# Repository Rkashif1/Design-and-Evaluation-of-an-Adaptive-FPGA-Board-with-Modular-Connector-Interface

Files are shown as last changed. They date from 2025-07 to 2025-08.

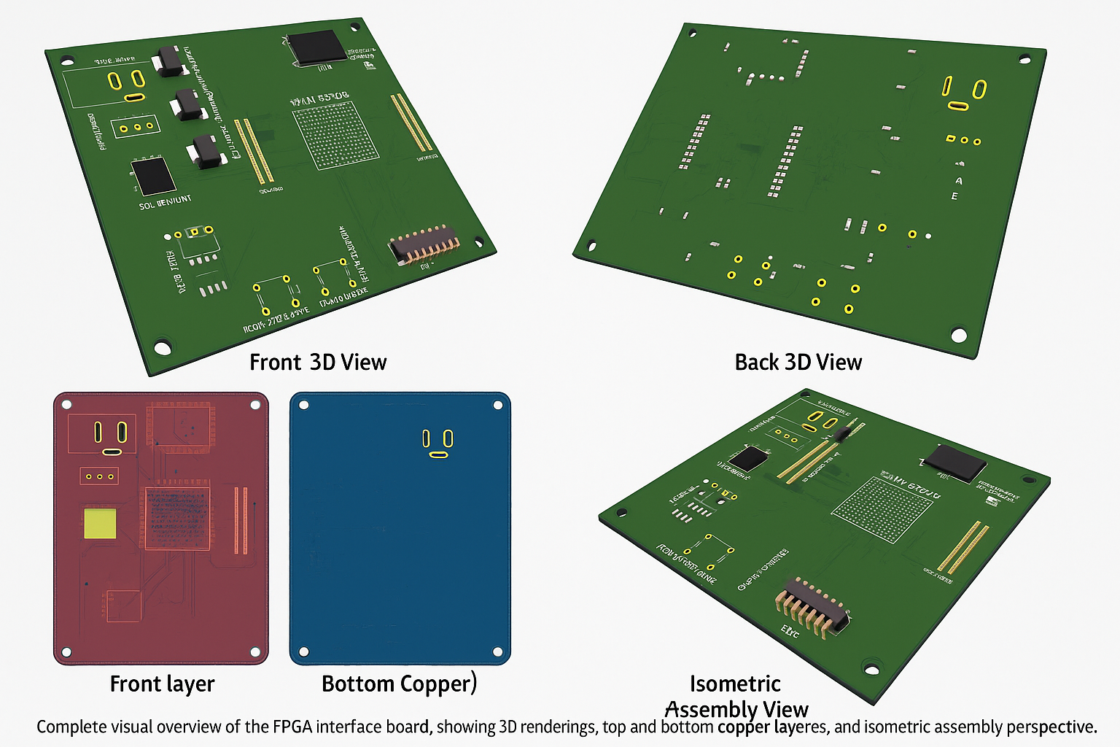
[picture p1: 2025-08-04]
Project_Refrence_Images/Others/FPGA Interface Board 3D Overview.png

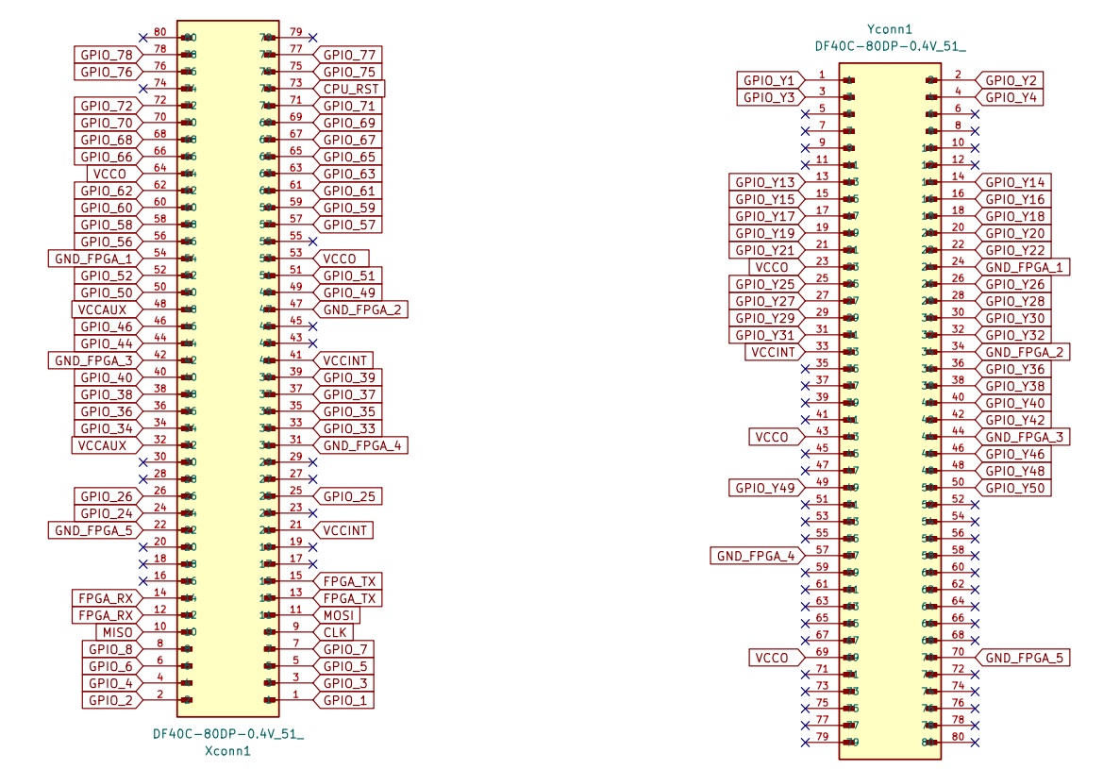
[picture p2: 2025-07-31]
Project_Refrence_Images/Schematics/DFC_Connectors.jpg

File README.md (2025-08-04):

**Design and Evaluation of an Adaptive FPGA Board with Modular Connector Interface**

This repository contains the complete project files for the development of an adaptive FPGA board designed to interface with various sensor and actuator peripherals through dual high-density connectors. The FPGA module is implemented using the Xilinx Spartan-7 XC7S25 and follows a modular architecture that allows it to be plugged into different motherboards for dynamic reconfiguration.

📁 Contents include:

KiCad schematic and PCB layout files

LaTeX report and documentation

Schematics and 3D board Refrence Images

🛠️ Key tools used: KiCad, Xilinx Vivado, Git, LaTeX

📌 Developed as part of an academic project demonstrating real-world modular hardware design and reconfigurable embedded systems.

FPGA Interface Board 3D Overview
*3D rendered view of the adaptive FPGA board featuring dual high-density connectors and a Spartan-7 FPGA*

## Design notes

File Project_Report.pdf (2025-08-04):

## Design and Evaluation of an Adaptive FPGA Board with Modular Connector Interface

Project Work by

### Kashif Raza

In Partial Fulfillment of the Requirements for the Degree of
Bachelor of Engineering - ELECTRONICS

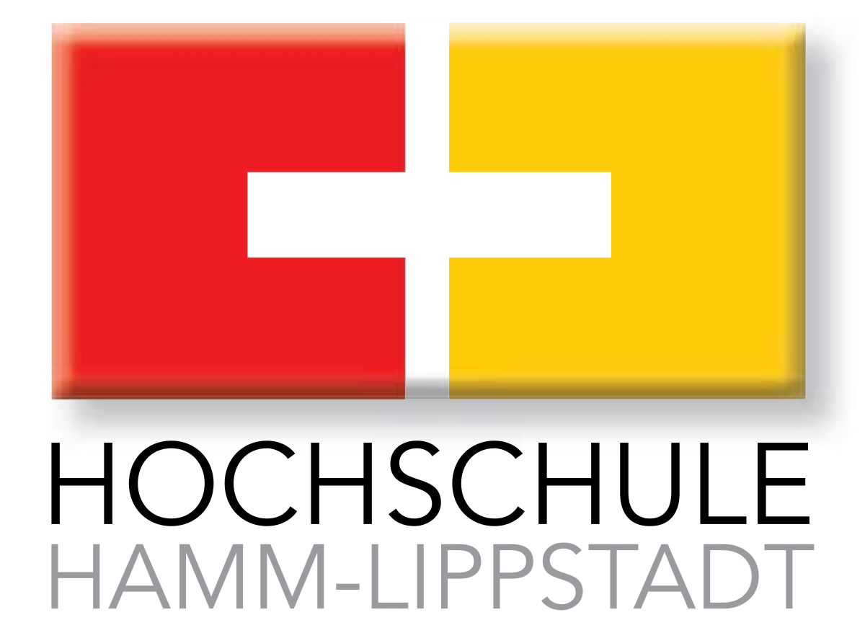
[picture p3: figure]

HOCHSCHULE HAMM-LIPPSTADT

First University Examiner: Prof. Dr. -Ing. Ali Hayek !!!!
Submission Date 31/07/2025

ii

© First University Examiner: Prof. Dr. -Ing. Ali Hayek

© !!!!

iii

### ACKNOWLEDGEMENTS

I would like to express my sincere appreciation to everyone who supported me in completing my project work. I am particularly thankful to my examiner, Professor Ali Hayek, for his continuous guidance and encouragement throughout the process. Through his courses on Hardware Engineering and Advanced Hardware Engineering, I gained the essential theoretical knowledge and practical understanding required to design and implement a custom FPGA-based adaptive board and develop a complete PCB layout.

Professor Hayek’s emphasis on precision and structured thinking helped me approach this project with a clear and calculated mindset. I am grateful for the academic environment provided by Hamm-Lippstadt University of Applied Sciences, which fostered my growth and enabled me to independently explore and apply concepts in real-world PCB and FPGA system design.

iv

### ABSTRACT

This project presents the design and implementation of an adaptive FPGA-based interface board centered on the Xilinx Spartan-7 XC7S25, developed as a compact, modular, and scalable platform for embedded systems and robotics applications. The primary goal was to identify and integrate the most suitable FPGA solution that balances performance, cost, toolchain accessibility, and long-term availability. After a comparative evaluation of multiple FPGA families, the Spartan-7 was selected for its modern 28 nm architecture, low power consumption, and full support within the free Vivado WebPACK environment. The board features two 80-pin DF40C high-density connectors that enable seamless integration with external motherboards or expansion units, along with support for DDR2 memory, SPI and UART communication, and dedicated interfaces for sensors and actuators. Configuration and debugging are facilitated through onboard USB-UART and JTAG interfaces, while basic I/O interaction is supported via LEDs and push buttons. Implemented on a multilayer PCB, the design ensures efficient signal routing, stable power delivery, and domain separation for reliable operation. Tailored for educational and prototyping contexts, the board accommodates typical robotics tasks such as line-following, obstacle detection, and servo control, offering a flexible and accessible foundation for FPGA-based system development.

v

### TABLE OF CONTENTS

Acknowledgements | iii
Abstract | | iv
Table of Contents | | v
List of Illustrations | | vi
Chapter I: Introduction | | 1
1.1 Motivation | | 1
Chapter II: Project Requirements and Design Goals | | 3
Chapter III: Selecting the Right FPGA Solution | | 4
Chapter IV: Features | | 7
Chapter V: Applications of the Adaptive FPGA Board | | 8
Chapter VI: Pin Mapping | 10
6.1 X-CONN Pin Mapping | 12
6.2 Y-CONN Pin Mapping | 14
Chapter VII: Peripherals | 16
Chapter VIII: Schematic and PCB Overview | 19
Chapter IX: Evaluation | 23
Chapter X: Future Work | 25
Chapter XI: Tools and Software Used | 27
Bibliography | 28

vi

### LIST OF ILLUSTRATIONS

Number | Page
3.1 Xilinx Spartan-7 FPGA Package | | | 6
9.1 Design Rule Check completed successfully | 24
8.1 Schematic: Power Management and Voltage Regulation Block | 31
8.2 Schematic: USB-UART and SPI Communication Interface Block | 32
8.3 Schematic: Xilinx JTAG Configuration Interface Block | 32
8.4 Schematic: External Memory Module Support Block | 33
8.5 Schematic: Reset and Power LED Indicator Block | 34
8.6 Schematic: Clock Generation with Crystal Oscillator | 35
8.7 Schematic: DF40C High-Density Connector Interface | 35
8.8 Schematic: Xilinx Spartan-7 FPGA Core Block | 36
8.9 3D View of Final PCB - Front Side | 37
8.10 3D View of Final PCB - Back Side | 38
8.11 Top View of Final PCB Layout | 39
8.12 Bottom View of Final PCB Layout | 40
8.13 Isometric View of the Assembled Board | 41
8.14 Layer Stackup | 42

C h a p t e r 1

### INTRODUCTION

In the field of embedded systems, Field Programmable Gate Arrays (FPGAs) play a crucial role due to their parallel processing capabilities, reconfigurability, and suitability for time-critical applications. Unlike microcontrollers, FPGAs offer hardware-level concurrency, making them ideal for robotics, signal processing, and control systems.

This project presents the design of an adaptive FPGA-based interface board built around the Xilinx Spartan-7 XC7S25. The board is developed as a modular platform to support a variety of sensor and actuator-driven systems. Key features include external DDR2 memory, SPI and UART communication interfaces, JTAG and USB-UART programming options, and onboard peripherals such as LEDs and push buttons. To facilitate expandability and integration, the board includes two 80-pin DF40c high-density connectors that allow reliable interfacing with external control units. A multilayer PCB layout is used to ensure clean separation of power, signal, and ground domains.

This document is organized to guide the reader through the complete development process. The initial chapters cover the motivation, design goals, and FPGA selection strategy. Subsequent sections describe the hardware features, application domains, and detailed pin mapping for both high-density connectors. The later chapters focus on peripheral integration, schematic and PCB layout overview, design evaluation, and future development directions, concluding with the tools used throughout the project.

### 1.1 Motivation

The motivation behind this project came from the growing demand for compact, modular hardware platforms suited for academic and prototyping environments. In university labs, developers often need to experiment with various sensors, actuators, and communication protocols. Designing a general-purpose adaptive board reduces the need to create custom hardware for each use case, saving time and increasing flexibility.

FPGAs, particularly from the Spartan-7 family, offer the reconfigurability, low power consumption, and logic capacity necessary for mid-range embedded applications. Unlike microcontrollers, they enable parallel processing and custom logic implementation, making them ideal for tasks that require real-time performance. To support clean integration with external systems, the board includes DF40c high-density connectors and is built on a multilayer PCB to ensure signal integrity and reduce noise. Robotics applications were a key focus, with dedicated sensors, actuators, and communication modules.

The project combines practical PCB design experience with embedded system development, resulting in a reusable FPGA-based platform tailored for academic, research, and robotics use cases.

C h a p t e r 2

### PROJECT REQUIREMENTS AND DESIGN GOALS

The goal of this project is to design a compact, low-power, and cost-effective embedded system based on the Xilinx Spartan-7 XC7S25 FPGA, tailored for educational, prototyping, and small-scale deployment use. The platform is designed to interface with a wide range of sensors, communication peripherals, and memory components, while remaining reusable and scalable.

A key requirement was selecting an FPGA with sufficient logic density, low power consumption, and broad I/O support, while ensuring compatibility with a free and accessible development toolchain. The Spartan-7 series met these criteria and supports features such as DDR2 memory, SPI, I²C, and

UART communication.

To maximize modularity, the board integrates high-density DF40c connectors for expansion with external modules like motor drivers or wireless interfaces. The layout also considers future scalability by supporting pin-compatible FPGA upgrades within the Spartan-7 family.

Essential onboard peripherals including push buttons, LEDs, and oscillator circuits—support development and debugging. The use of a multilayer PCB enhances signal integrity and power distribution. All components were chosen with long-term availability in mind, making the board suitable for replication in academic and research settings.

The project’s design goals focused on building a reusable and expandable embedded platform with a strong emphasis on performance, cost-efficiency, educational usability, and peripheral integration. These requirements drove every architectural and component-level decision made throughout the course of development.

C h a p t e r 3

### SELECTING THE RIGHT FPGA SOLUTION

Choosing the most suitable FPGA for a development board requires careful evaluation of multiple factors: logic capacity, I/O availability, toolchain compatibility, power consumption, costeffectiveness, and long-term availability. These considerations become even more critical when designing an educational or prototyping-focused platform where usability, affordability, and futureproofing are essential.

In the early stages of this project, multiple FPGA families were considered, including Intel’s Cyclone IV and V series, Lattice’s iCE40 lineup, and Xilinx’s Spartan-6 and Spartan-7 families. Each candidate offered unique advantages and trade-offs, which were evaluated across the metrics shown in Table 3.1.

Table 3.1: Comparison of FPGA Families Considered

FPGA Family | Logic Cells | Block RAM | Tool Support | Power | Open Source?
Intel Cyclone IV Intel Cyclone V Lattice iCE40 HX8K Xilinx Spartan-6 LX25 Xilinx Spartan-7 XC7S25 | 22,000 30,000 7,680 24,051 23,360 | 1.2 Mbits 2.5 Mbits 128 Kbits 936 Kbits 1,600 Kbits | Quartus Quartus Prime Yosys + nextpnr ISE (Legacy) Vivado | Moderate Moderate-High Very Low Moderate Low | No No Yes No No

The Xilinx Spartan-7 XC7S25-1FTGB196C FPGA was selected for this project due to its strong balance of modern architecture, low power consumption, flexible packaging, and long-term scalability. Among several evaluated options—such as Intel Cyclone IV/V, Lattice iCE40, and the older Spartan-6, the Spartan-7 family stood out as a future-ready and efficient solution that is well-suited for embedded development tasks. Built on a 28 nm process node, Spartan-7 FPGAs benefit from lower dynamic power consumption and support higher operational clock frequencies, all while maintaining a compact footprint. This is particularly advantageous in thermally-constrained or battery-powered embedded systems, as the device’s core voltage (VCCINT) is approximately 1.0 V, reducing overall thermal output and enabling efficient energy usage [14].

Technical Capabilities

The XC7S25 variant includes:

- 23,360 logic cells for implementing complex digital designs
- 1,600 Kbits of block RAM for buffering and temporary storage
- 80 DSP slices, allowing moderate digital signal processing operations

It supports interfacing with DDR2 SDRAM [13] and a wide range of I/O standards including LVCMOS, LVTTL, and LVDS [14]. These features make it ideal for control logic, memory expansion, and sensor or communication interfacing.

In addition to its base architecture, the Spartan-7 series includes several advanced integrated features that enhance its utility in complex applications. The inclusion of XADC allows for onchip voltage and temperature monitoring, which can be accessed via JTAG or user logic, aiding system diagnostics and dynamic reconfiguration. The device also incorporates MMCM and PLL clocking blocks, known as clock management tiles (CMT), which provide stable multi-domain clock generation critical for complex timing requirements. These features are all built on a unified 7-Series logic architecture, which is consistent across other Xilinx families such as Artix-7, Kintex-7, and Virtex-7, allowing for future design migration and scalability [14].

From a hardware design perspective, the FTGB196 BGA package was a strategic choice. Despite its compact size, it offers a sufficient number of I/O pins, allowing for high GPIO density while simplifying layout in multilayer PCB designs. Its fine-pitch ball grid array supports tight routing and reliable signal integrity, especially when paired with high-speed board-to-board connectors. The package’s compact footprint helps maintain a small overall board size while ensuring all necessary connections for sensors, memory, and communication peripherals can be made effectively [6].

Spartan-7 also proves to be a highly suitable option for academic and prototype-oriented projects. It is fully supported by the free Vivado WebPACK toolchain [16], which includes all essential features such as IP Integrator, constraint-based synthesis, simulation, and bitstream generation. This eliminates the need for costly software licenses, making it accessible to students and researchers. Compared to more resource-intensive solutions like Intel’s Cyclone V or Altera’s Stratix series, Spartan-7 enables a smoother learning curve without sacrificing critical FPGA development capabilities.

Scalability and Long-Term Availability

In terms of scalability and availability, the XC7S25 model is readily stocked by major global distributors including Digi-Key and Mouser [15]. This ensures that projects relying on the chip can continue production without facing supply shortages. Additionally, the XC7S25 is often pin-compatible with larger Spartan-7 models such as the XC7S50, which enables seamless upgrades

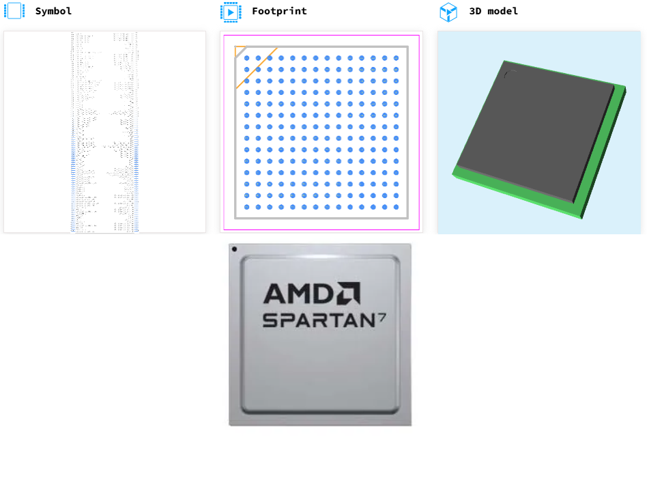
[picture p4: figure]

Figure 3.1: Xilinx Spartan-7 FPGA Package

in case future iterations of the project require more logic or memory resources. This upgradability reduces the need for PCB redesign and extends the long-term viability of the system architecture.

The Spartan-7 XC7S25 presents a well-rounded, accessible, and forward-compatible platform that meets the performance and flexibility demands of modern embedded system development. Its architectural features, robust toolchain support, and practical packaging make it a strong candidate for both initial prototyping and scaled deployment.

C h a p t e r 4

### FEATURES

The adaptive FPGA board was designed with a focus on modularity, flexibility, and expandability. Below are the key features that make this board suitable for embedded systems, robotics, and academic research:

- Xilinx Spartan-7 XC7S25 FPGA: Provides a strong balance of logic resources, low power

consumption, and modern toolchain support.

- Multilayer PCB Design: Ensures optimized signal integrity and power distribution across

functional layers.

- Two DF40c 80-pin High-Density Connectors: Allow secure and compact plug-and-play

connection to a motherboard or expansion board.

- Support for External DDR2 Memory: Enables high-speed memory interfacing for real-

time and data-intensive applications.

- Multiple Communication Interfaces: Includes dedicated lines for SPI, I2C, and UART

protocols to interface with various peripherals.

- JTAG Interface: Allows for easy programming and debugging of the FPGA using standard

tools.

- USB-UART Bridge: Facilitates serial communication with the FPGA for monitoring and

control.

- Onboard LEDs and Push Buttons: Offer user interaction and visual debugging during

testing and development.

- Peripheral Connector Support: Headers available for IR sensors, servo motors, ultrasonic

sensors, and OLED display.

- Compact and Student-Friendly Layout: Optimized for prototyping and academic use,

while remaining scalable for more complex designs.

- Cost-Efficient and Readily Available Components: Ensures that the board is affordable

and easy to reproduce for classroom or lab use.

C h a p t e r 5

### APPLICATIONS OF THE ADAPTIVE FPGA BOARD

The adaptive FPGA board has been designed to serve a wide range of applications in embedded systems, robotics, and automation. Because of its flexible I/O, memory support, and robust connectivity, it is suitable for both educational and real-world use cases. FPGAs have been increasingly adopted in domains where deterministic timing, parallel processing, and hardware-level customization are required [5, 9].

Some of the most relevant applications of this board are as follows:

- Line-Following Robot (LFR): Using onboard IR sensors, the FPGA can process line contrast

and control wheel motors accordingly. FPGAs are particularly well-suited for real-time signal processing required in robotics path planning [9].

- Obstacle Avoidance System: With the help of ultrasonic sensors (e.g., HC-SR04), the board

can be programmed to detect obstacles and react in real time by altering motor directions or triggering alerts.

- Robotic Arm Control: Through PWM generation on the FPGA, users can control servo

motors (such as SG90) for precise movement. The hardware-based timing control makes FPGAs better at handling simultaneous axis movement than software-based microcontrollers.

- Environmental Monitoring System: The board supports DHT22 sensors for temperature

and humidity monitoring, enabling use in smart home or industrial automation settings.

- IoT Gateway Node: By integrating with Wi-Fi (ESP8266) or Bluetooth (HC-05) modules

through UART or SPI, the FPGA board can function as a local processing and communication node in IoT systems.

- Data Acquisition and Display System: Data collected from sensors can be visualized

using the connected OLED (SSD1306) display, controlled via I2C from the FPGA, ideal for laboratory test setups.

- Educational FPGA Trainer Kit: With all essential interfaces onboard, the board is perfect

for teaching students about digital design, interfacing, and embedded system development.

The deterministic and reconfigurable nature of FPGAs makes them highly suitable for embedded control systems, especially in scenarios where flexibility and real-time processing are required [4].

C h a p t e r 6

### PIN MAPPING

The pin mapping of the adaptive FPGA board is a critical part of its overall architecture. To establish reliable communication between the FPGA and external peripherals (such as sensors, actuators, and user interfaces), the board features two 80-pin DF40c high-density connectors, designated as X-CONN and Y-CONN.

In our design, the male connectors are soldered onto the adaptive FPGA board, while the corresponding female connectors are present on a separate motherboard that carries all the peripheral components—such as IR sensors, servo motors, distance sensors, seven-segment displays, keypads, BLE modules, and more. This physical arrangement allows the adaptive board to be plugged directly into the motherboard. The DF40c connectors act as a bridge, allowing every pin on the adaptive board to connect precisely with the component it is intended to control or read from.

Each pin on the male connector is mapped either to an FPGA general-purpose I/O pin or to a dedicated communication, power, or control signal. By referencing the detailed pin mapping tables for both X-CONN and Y-CONN (provided in the following pages), users can quickly identify which peripheral connects to which FPGA pin. This structured mapping supports modular development and ensures long-term maintainability and scalability.

Beyond the X-CONN and Y-CONN mappings, several other connections are also established on the adaptive board:

- Power Management: Multiple voltage domains are supported across the board. Pins are

allocated for VCCINT (1.3V), VCCAUX (1.8V), and VCCO (3.3V). These voltages power both the FPGA core and the I/O banks. Ground connections (GND) are distributed throughout both connectors to ensure stable power delivery and signal integrity.

- Communication Interfaces:

– SPI Interface: Includes SCK, MISO, and MOSI lines routed to the FPGA for communicating with devices like LoRa modules, flash memory, or sensor hubs.

– UART Lines: RX and TX lines are connected for BLE (HC-05) and Wi-Fi (ESP8266) modules, enabling wireless communication.

– I

2C Bus: SDA and SCL pins are provided for interfacing with devices such as OLED

displays or real-time clocks.

- Input/Output Peripherals:

– Multiple GPIO pins are assigned to LEDs (LED1–LED16), push buttons (PB1–PB5), and switches (SW1–SW16).

– PWM-capable GPIOs are used for controlling servo motors and for generating signals for the motor driver’s IN and EN pins.

- Reset and Clocking:

– A dedicated reset pin (CPU_RST) is connected to a push button to reset the FPGA.

– An external clock pin (CLK) is allocated for synchronous logic and communication protocols like SPI.

- Analog and Mixed-Signal Interfaces:

– ADC reference voltage pins (ADC VREF+ and VREF-) are mapped for precise analog measurements from sensors such as LDR, vibration sensors, and microphones.

This comprehensive pin mapping strategy ensures that the board can be used across a wide range of embedded systems and robotics projects without needing redesigns for each application. By simply plugging the adaptive board into a motherboard carrying the necessary peripherals, the system becomes ready for programming, prototyping, or deployment.

Below are the detailed pin mappings for both X-CONN and Y-CONN connectors:

### 6.1 X-CONN Pin Mapping

Female Connector Pin | Male Connector Pin | Peripheral name | FPGA PIN
X1 | X1 | Keypad R1 | GPIO_1
X2 | X2 | Keypad R2 | GPIO_2
X3 | X3 | Keypad R3 | GPIO_3
X4 | X4 | Keypad R4 | GPIO_4
X5 | X5 | Keypad C1 | GPIO_5
X6 | X6 | Keypad C2 | GPIO_6
X7 | X7 | Keypad C3 | GPIO_7
X8 | X8 | Keypad C4 | GPIO_8
X9 | X9 | SPI SCK | CLK
X10 | X10 | SPI MISO | MISO
X11 | X11 | SPI MOSI | MOSI
X12 | X12 | HC05 BLE RXD | FPGA_RX
X13 | X13 | HC05 BLE TXD | FPGA_TX
X14 | X14 | ESP8266 WLAN RXD | FPGA_RX
X15 | X15 | ESP8266 WLAN TXD | FPGA_TX
X16 | X16 | GPIO 1 | X
X17 | X17 | GPIO 2 | X
X18 | X18 | GPIO 3 | X
X19 | X19 | GPIO 4 | X
X20 | X20 | NC | NC
X21 | X21 | VIN | VCCINT
X22 | X22 | GND | GND_FPGA_5
X23 | X23 | NC | NC
X24 | X24 | LED 1 | GPIO_24
X25 | X25 | LED 2 | GPIO_25
X26 | X26 | LED 3 | GPIO_26
X27 | X27 | GPIO 5 | X
X28 | X28 | GPIO 6 | X
X29 | X29 | GPIO 7 | X
X30 | X30 | GPIO 8 | X
X31 | X31 | GND | GND_FPGA_4
X32 | X32 | VIN | VCCAUX
X33 | X33 | LED 4 | GPIO_33
X34 | X34 | LED 5 | GPIO_34
X35 | X35 | LED 6 | GPIO_35
X36 | X36 | LED 7 | GPIO_36
X37 | X37 | LED 8 | GPIO_37
X38 | X38 | LED 9 | GPIO_38
X39 | X39 | LED 10 | GPIO_39
X40 | X40 | LED 11 | GPIO_40
X41 | X41 | VIN | VCCINT
X42 | X42 | GND | GND_FPGA_3

Female Connector Pin | Male Connector Pin | Peripheral name | FPGA PIN
X43 | X43 | NC | NC
X44 | X44 | I2C SDA | GPIO_44
X45 | X45 | NC | NC
X46 | X46 | I2C SCL | GPIO_46
X47 | X47 | GND | GND_FPGA_2
X48 | X48 | VIN | VCCAUX
X49 | X49 | LED 12 | GPIO_49
X50 | X50 | LED 13 | GPIO_50
X51 | X51 | LED 14 | GPIO_51
X52 | X52 | LED 15 | GPIO_52
X53 | X53 | VSYS | VCCO
X54 | X54 | GND | GND_FPGA_1
X55 | X55 | NC | NC
X56 | X56 | Switch 1 | GPIO_56
X57 | X57 | Switch 2 | GPIO_57
X58 | X58 | Switch 3 | GPIO_58
X59 | X59 | Switch 4 | GPIO_59
X60 | X60 | Switch 5 | GPIO_60
X61 | X61 | Switch 6 | GPIO_61
X62 | X62 | Switch 7 | GPIO_62
X63 | X63 | Switch 8 | GPIO_63
X64 | X64 | VSYS | VCCO
X65 | X65 | Switch 9 | GPIO_65
X66 | X66 | Switch 10 | GPIO_66
X67 | X67 | Switch 11 | GPIO_67
X68 | X68 | Switch 12 | GPIO_68
X69 | X69 | Switch 13 | GPIO_69
X70 | X70 | Switch 14 | GPIO_70
X71 | X71 | Switch 15 | GPIO_71
X72 | X72 | Switch 16 | GPIO_72
X73 | X73 | RESET | CPU_RST
X74 | X74 | NC | NC
X75 | X75 | Push button 1 | GPIO_75
X76 | X76 | Push button 2 | GPIO_76
X77 | X77 | Push button 3 | GPIO_77
X78 | X78 | Push button 4 | GPIO_78
X79 | X79 | NC | NC
X80 | X80 | NC | NC

### 6.2 Y-CONN Pin Mapping

Female Connector Pin | Male Connector Pin | Peripheral name | FPGA PIN
Y1 | Y1 | Color sensor S0 | GPIO_Y1
Y2 | Y2 | Moisture sensor signal | GPIO_Y2
Y3 | Y3 | Color sensor S1 | GPIO_Y3
Y4 | Y4 | Color sensor S2 | GPIO_Y4
Y5 | Y5 | GPIO 9 | X
Y6 | Y6 | GPIO 10 | X
Y7 | Y7 | GPIO 11 | X
Y8 | Y8 | GPIO 12 | X
Y9 | Y9 | GPIO 13 | X
Y10 | Y10 | GPIO 14 | X
Y11 | Y11 | GPIO 15 | X
Y12 | Y12 | GPIO 16 | X
Y13 | Y13 | Buzzer | GPIO_Y13
Y14 | Y14 | Color sensor S3 | GPIO_Y14
Y15 | Y15 | Seven segment display (a) | GPIO_Y15
Y16 | Y16 | Seven segment display (b) | GPIO_Y16
Y17 | Y17 | Seven segment display (c) | GPIO_Y17
Y18 | Y18 | Seven segment display (d) | GPIO_Y18
Y19 | Y19 | Seven segment display (e) | GPIO_Y19
Y20 | Y20 | Seven segment display (f) | GPIO_Y20
Y21 | Y21 | Seven segment display (g) | GPIO_Y21
Y22 | Y22 | Color sensor Out | GPIO_Y22
Y23 | Y23 | VCC / +3V3 | VCCO
Y24 | Y24 | GND | GND_FPGA_1
Y25 | Y25 | Seven segment display (a1) | GPIO_Y25
Y26 | Y26 | Seven segment display (a2) | GPIO_Y26
Y27 | Y27 | Seven segment display (a3) | GPIO_Y27
Y28 | Y28 | Seven segment display (a4) | GPIO_Y28
Y29 | Y29 | Seven segment display (a5) | GPIO_Y29
Y30 | Y30 | Seven segment display (a6) | GPIO_Y30
Y31 | Y31 | Seven segment display (a7) | GPIO_Y31
Y32 | Y32 | Seven segment display (a8) | GPIO_Y32
Y33 | Y33 | GND | GND_FPGA_2
Y34 | Y34 | VCC | VCCINT
Y35 | Y35 | NC | NC
Y36 | Y36 | Motor driver IN2 | GPIO_Y36
Y37 | Y37 | NC | NC
Y38 | Y38 | Left IR sensor pin | GPIO_Y38
Y39 | Y39 | NC | NC
Y40 | Y40 | Right IR sensor pin | GPIO_Y40
Y41 | Y41 | NC | NC
Y42 | Y42 | Motor driver IN4 | GPIO_Y42

Female Connector Pin | Male Connector Pin | Peripheral name | FPGA PIN
Y43 | Y43 | VCC / +3V3 | VCCO
Y44 | Y44 | GND | GND_FPGA_3
Y45 | Y45 | NC | NC
Y46 | Y46 | PIR motion sensor | GPIO_Y46
Y47 | Y47 | NC | NC
Y48 | Y48 | LoRa G0 | GPIO_Y48
Y49 | Y49 | LoRa CS | GPIO_Y49
Y50 | Y50 | LoRa RST | GPIO_Y50
Y51 | Y51 | RFID CS | X
Y52 | Y52 | RFID RST | X
Y53 | Y53 | NC | NC
Y54 | Y54 | DHT22 temperature sensor pin | X
Y55 | Y55 | NC | NC
Y56 | Y56 | NC | NC
Y57 | Y57 | GND | GND_FPGA_4
Y58 | Y58 | NC | NC
Y59 | Y59 | Distance sensor trigger | D6
Y60 | Y60 | Motor driver IN1 | D1
Y61 | Y61 | Left servo signal | D5
Y62 | Y62 | Motor driver EnA | D0
Y63 | Y63 | Motor driver IN3 | D4
Y64 | Y64 | NC | NC
Y65 | Y65 | Motor driver EnB | D3
Y66 | Y66 | NC | NC
Y67 | Y67 | Right servo signal | D2
Y68 | Y68 | NC | NC
Y69 | Y69 | VCC / +3V3 | VCCO
Y70 | Y70 | GND | GND_FPGA_5
Y71 | Y71 | ADC VREF + | X
Y72 | Y72 | ADC VREF - | X
Y73 | Y73 | LDR | A0
Y74 | Y74 | Piezo vibration sensor | A4
Y75 | Y75 | Potentiometer 2 | A1
Y76 | Y76 | Distance sensor echo | D20
Y77 | Y77 | LED 16 | A2
Y78 | Y78 | Push button 5 | D21
Y79 | Y79 | Microphone analog pin | A3
Y80 | Y80 | NC | NC

C h a p t e r 7

### PERIPHERALS

This section details the critical peripherals designed into the adaptive FPGA board. Each component is selected to maximize modularity, performance, and suitability for reconfigurable and embedded system applications.

Power Management Circuit

The power management subsystem is responsible for regulating, distributing, and protecting voltage supplies to the various blocks on the FPGA board. It typically includes low-dropout voltage regulators (LDOs), Schottky diodes, and decoupling capacitors. This design enables the board to derive multiple regulated rails—such as 3.3V for I/O, 1.2V for FPGA core, and 2.5V for auxiliary peripherals—from a single USB 5V input or external supply. Power sequencing is critical: the FPGA core voltage must be stabilized before auxiliary and I/O voltages are enabled, to prevent latch-up or undefined behavior during configuration. In your adaptive board, this stable power foundation ensures safe operation of high-speed interfaces like DDR2 and SPI, and also protects the FPGA fabric during boot and resets. A power-good LED is connected to the 3.3V line to indicate readiness, assisting in visual verification during testing or production. Without a stable power subsystem, the FPGA logic may misconfigure or fail to boot entirely [2].

High-Density DF40C Connectors

Your board includes two DF40C 80-pin high-density board-to-board connectors that form the central bridge between the adaptive FPGA module and the external motherboard. These connectors expose nearly all general-purpose I/Os, communication lines, and power rails from the FPGA to the external system. This modular approach allows the same FPGA core to interface with different hardware subsystems—such as robotics controllers, sensors, or actuators—by simply plugging into a different baseboard. The DF40C series from Hirose is known for high-speed signal support, compact pitch (0.4 mm), and robust mechanical locking. The connectors make the board ideal for stacking applications and ensure impedance-controlled routing suitable for DDR2, SPI, and other synchronous interfaces. In this project, the connectors provide the main pathway for SPIcontrolled OLED displays, I2C sensor arrays, IR-based obstacle sensors, or even actuator control via UART-based motor drivers [10].

JTAG Interface

The Joint Test Action Group (JTAG) interface is essential for in-system configuration and debugging of the FPGA. It enables boundary-scan testing, logic configuration through bitstream upload, and post-configuration signal analysis. In your design, a standard 6-pin JTAG header is connected directly to the Spartan-7 FPGA and routed to the top layer for easy access. This interface works with tools like Xilinx Vivado and iMPACT to program the board and observe internal logic. For instance, when verifying the DDR2 controller or the SPI communication core, the JTAG allows you to set breakpoints, toggle test inputs, or read internal registers using Chipscope or ILA (Integrated Logic Analyzer) IPs. The presence of JTAG simplifies the development cycle and eliminates the need for external flash or USB interfaces during firmware prototyping [16].

USB-UART and SPI Communication Interfaces

The board includes dual communication interfaces: USB-UART and SPI. The USB-UART bridge (such as a CP2102 or FT2232) connects the FPGA to a host PC via a virtual COM port, allowing real-time data exchange, logging, and user input through terminal applications like PuTTY. In your case, this is especially useful for logging events like configuration status, memory usage, or sensor data from the external motherboard. SPI (Serial Peripheral Interface), on the other hand, is a synchronous, full-duplex protocol ideal for interfacing with OLED displays, shift registers, and ADCs. On your adaptive board, the SPI lines are routed through the DF40C connector, enabling modular attachment to SPI-based peripherals like OLED or LoRa modules. The separation of control (UART) and sensor-actuator communication (SPI) ensures modularity, clarity in signal flow, and robust debugging [12, 7].

Memory Module Support

The board supports external DDR2 memory via a dedicated memory interface connected to the Spartan-7. The DDR2 SDRAM allows high-speed, large-volume data storage and buffering, which is essential for applications requiring frame buffering, temporary sensor data storage, or real-time signal processing. For example, in a use case where the FPGA is controlling a display or capturing sensor readings at high frequency, internal BRAM is insufficient. The DDR2 interface is implemented using the Xilinx MIG (Memory Interface Generator) IP, which handles timing constraints, clock domain synchronization, and latency management. This memory system enables your project to scale into more complex workloads, including lightweight video processing, packet buffering in IoT gateways, or real-time motor feedback systems [13].

LED Indicator and Reset Buttons

The board includes a single LED and two push buttons. The LED is connected to the 3.3V line through a resistor and serves as a power indicator. This is useful for basic health checking and user feedback, especially when operating headless (without PC connection). One push button is wired to the configuration reset pin, enabling reloading of the FPGA bitstream during debugging or recovery. The second button performs an FPGA CPU reset, which can be used to restart logic cores like MicroBlaze or user-defined FSMs without reprogramming the entire chip. Both buttons are active-low and debounced either through hardware (RC network) or logic (FPGA). In your modular system, these buttons help reset the board before re-attaching to new daughterboards or clearing memory states during demos [11, 8].

Crystal Oscillator

A 50 MHz crystal oscillator is included on the board to provide a clean, stable reference clock for the FPGA. The Spartan-7’s global clock input receives this signal and may use MMCMs (Mixed-Mode Clock Managers) or PLLs to derive secondary clocks (e.g., 100 MHz for memory, 25 MHz for SPI). Clock stability is critical for synchronous systems where timing violations can lead to metastability or data corruption. Your oscillator ensures reliable timing for DDR2 memory access, serial protocol timings, and logic state transitions. For example, when reading from sensors over SPI and writing to DDR2 buffers, synchronized and phase-aligned clocking ensures data coherency. The crystal is selected for low jitter and startup delay, suitable for both industrial and academic use [1].

FPGA Core: Xilinx Spartan-7

The computational engine of the board is the Xilinx Spartan-7 XC7S25-1FTGB196C FPGA. This 28nm CMOS programmable logic device offers 23,360 logic cells, 120 user I/Os, multiple block RAMs (BRAM), and dedicated DSP slices. It also includes integrated clock managers, high-speed serial transceivers, and support for MicroBlaze soft-core processors. In your adaptive system, this FPGA enables custom digital logic for tasks such as real-time sensor data processing, protocol bridging, and motor control. Its reconfigurability allows reuse across multiple applications—robotic control, IoT edge computation, or educational labs—by reprogramming the logic fabric. The Spartan-7 strikes a balance between cost, power, and capability, making it ideal for modular, reusable FPGA projects like yours [15].

C h a p t e r 8

### SCHEMATIC AND PCB OVERVIEW

This chapter provides a comprehensive description of the schematic design and PCB layout implemented for the adaptive FPGA board. The schematic is divided into functional blocks, each of which serves a specific purpose in the electrical and system-level design. These blocks are discussed below in the order they appear in the complete system.

The first subsystem is the Power Management and Voltage Regulation Block, which supplies the core voltage rails required by the FPGA and auxiliary components. The design includes low-dropout voltage regulators that convert a 5V USB input into stable 3.3V and 1.2V outputs. Proper decoupling capacitors are placed near each power pin, and the 3.3V line is connected to an indicator LED that signals the board’s power status. Input protection is provided by reverse-polarity diodes and inrush current-limiting resistors. This block ensures voltage stability and startup safety and lays the electrical foundation for all downstream modules. This block is shown in the Appendix as Figure 8.1.

The USB-UART and SPI Communication Block combines two vital communication protocols. The USB-UART section allows serial communication between the host computer and the FPGA, enabling terminal-based debugging and firmware logging. The SPI section enables the FPGA to control peripherals such as OLED displays and sensors. Pull-up resistors are included for SPI signal integrity, and all lines are routed through the DF40C connectors to external modules. The combined communication subsystem provides a flexible interface for both control and data flow. You can see the corresponding schematic in Figure 8.2 in the Appendix.

The JTAG Interface Block provides the programming and debugging entry point to the FPGA. It includes a 6-pin standard JTAG connector wired directly to the Spartan-7’s configuration pins. This block allows the user to upload bitstreams, perform boundary-scan testing, and use Xilinx debugging tools like Vivado’s Integrated Logic Analyzer. Proper signal terminations ensure clean JTAG clocking and reliable operation during configuration. This block is illustrated in Figure 8.3 in the Appendix.

The Memory Module Block includes routing for external DDR2 SDRAM, although the module is optional in this version. Control lines, address buses, and data I/Os are all grouped for synchronous timing and routed from the FPGA to the memory footprint. The goal of this module is to support data buffering for high-throughput applications in future versions of the board. The schematic layout for this module is shown in Figure 8.4 in the Appendix.

The Reset and LED Block features two push-buttons and one indicator LED. One push-button is connected to the FPGA configuration reset pin, and the other to the system reset input for internal soft-core processors like MicroBlaze. The LED is connected through a resistor to the 3.3V rail and confirms power delivery visually. These I/O elements are essential for manual testing, debugging, and system reinitialization. This schematic can be reviewed in Figure 8.5 in the Appendix.

The Clock Generation Block consists of a 50 MHz crystal oscillator connected to the FPGA’s global clock input. This stable reference clock feeds the Mixed-Mode Clock Manager (MMCM) inside the Spartan-7, which can then generate other required clock frequencies for different modules. Proper load capacitors and series resistors are included to ensure stable startup and reduce phase noise. This subsystem is critical for synchronous design and is depicted in Figure 8.6 in the Appendix.

The DF40C Connector Block implements the two 80-pin Hirose DF40C male connectors that allow the adaptive FPGA board to plug into a larger motherboard. All communication signals (SPI, UART, I2C), GPIOs, and power rails are routed through these connectors. The horizontal spacing between the connectors is 43.18 mm, matching the layout of the Arduino Portenta breakout board, ensuring mechanical and electrical compatibility. These connectors are the interface backbone that enables the board’s adaptive capabilities. The schematic is included in Figure 8.7 in the Appendix.

Lastly, the FPGA Core Block features the Xilinx Spartan-7 XC7S25 FPGA in an FTGB196 BGA package. It is connected to three separate power domains: VCCINT (1.2V core voltage), VCCAUX (2.5V auxiliary), and VCCIO (3.3V I/O). The block also includes all necessary configuration, global clock, and system reset lines. Most of the general-purpose I/O pins are routed through the DF40C connectors, allowing the board to adapt to various external peripheral arrangements. Proper pull-up and pull-down resistors are added to critical configuration pins such as INIT_B, DONE, and PROGRAM_B to ensure stable boot behavior and avoid floating logic states. This block serves as the heart of the adaptive system, enabling full reprogrammability and user-defined logic. The complete schematic for the FPGA core can be found in Figure 8.8 in the Appendix.

Following the completion of the schematic design, the next phase in the development process was the layouting. The transition from schematic to layout required careful consideration of electrical connectivity, mechanical constraints, component placement, and signal integrity. The board layout was created to house the Xilinx Spartan-7 XC7S25 FPGA along with all supporting peripherals, including power regulation circuits, communication interfaces, memory, clock sources, user I/O, and high-density connectors.

The first step in PCB layout involved defining the board outline and establishing the mechanical constraints dictated by the two DF40C high-density connectors. These connectors were placed precisely 43.18 mm apart to ensure compatibility with an external motherboard, similar to the Arduino Portenta breakout board. Mounting holes and connector footprints were then placed in accordance with the schematic, followed by strategic arrangement of core components such as voltage regulators, the JTAG interface, memory pads, and oscillator modules.

Once the component placement was finalized, the board stack-up was defined. Unlike simpler designs that rely on 2- or 4-layer PCBs, this adaptive FPGA board was implemented on a high-density 10-layer PCB. This multi-layer configuration allowed for optimized routing, dedicated power and ground planes, and controlled impedance paths for high-speed signals. The stack-up included alternating signal layers with interleaved power and ground planes to reduce electromagnetic interference (EMI) and crosstalk while maintaining electrical isolation between critical domains such as VCCINT, VCCAUX, and VCCIO.

The routing of the board was done using KiCad’s built-in routing tool, following custom rules for trace width, spacing, and via sizes. Important high-speed connections—like the ones used for the DDR2 memory and clock signals—were routed with carefully measured lengths to ensure they remain synchronized. In some cases, zig-zag or meandered traces were used to match signal timing. For signals that require high precision, like USB data lines, the traces were routed as balanced pairs on internal layers to reduce noise and maintain reliable communication.

The use of a ball-grid array (BGA) package for the Spartan-7 FPGA introduced significant routing challenges. With 196 balls and a high number of general-purpose I/O (GPIO) signals, careful fanout planning was essential. Blind, buried, and microvias were employed to escape inner balls and to reduce congestion under the BGA. Several inner layers were allocated specifically to facilitate this routing, providing additional channels for signals that could not be routed on outer layers. The inclusion of such via types enabled successful breakout and routing of all necessary FPGA signals to their corresponding blocks.

In addition to signal routing, several layers were reserved as solid planes for power distribution and grounding. This provided a low-impedance path for power delivery and improved thermal performance. Decoupling capacitors were placed as close as possible to the power pins of the FPGA and other active components, following standard high-speed design practices. Special attention was given to the oscillator block and clock lines, which were routed using short, shielded paths to minimize jitter and phase noise.

The visual inspection and review were complemented by 3D renderings of the board, which provided spatial verification of component heights, mounting hole clearance, and connector alignment. Screenshots of these 3D models are presented in Figures 8.9 to 8.13 in the Appendix for visual confirmation.

A major challenge faced during the PCB phase was the routing congestion caused by the dense peripheral configuration and the complexity of the FPGA chip. The abundance of signals, tight component spacing, and need for signal integrity required extensive layer planning and iterative routing. This phase was the most time-consuming and technically demanding part of the design, as even minor misroutes could cause timing issues, configuration failures, or mechanical misalignment.

Despite the challenges, the board was successfully routed, reviewed, and exported as Gerber files for manufacturing. The result is a professionally laid out, multi-layer PCB that meets the mechanical and electrical demands of an adaptive, reprogrammable embedded system. The design reflects a careful balance between technical precision and practical limitations of prototype development within the academic timeline.

C h a p t e r 9

### EVALUATION

After completing the PCB layout in KiCad, several evaluation steps were undertaken to validate both the electrical correctness and mechanical compatibility of the adaptive FPGA board. The first step involved running the built-in Design Rule Check (DRC) tool in the KiCad PCB editor. The DRC report, as shown in Figure 9.1, confirmed zero errors in the design, indicating that the trace widths, clearances, and via dimensions all adhered to the electrical constraints. Although some warnings were generated, mostly concerning the silkscreen layer, such as overlapping labels or proximity of silkscreen text to the board edge, these were acknowledged but not resolved due to time constraints, as they do not impact functionality or manufacturability.

Following the DRC validation, one of the most critical evaluations involved verifying the placement and alignment of the two high-density 80-pin DF40C male connectors on the bottom side of the adaptive FPGA board. These connectors form the primary physical and electrical bridge between the FPGA module and a separate motherboard that hosts peripherals like sensors, actuators, and communication bridges. To ensure successful interfacing, the connectors must match exactly with corresponding female connectors on the motherboard, both in horizontal spacing and vertical alignment. Any deviation in position could lead to mechanical failure or unreliable electrical contact.

To guide this mechanical alignment, the layout of the Arduino Portenta H7 breakout board was used as a dimensional reference. Although this project does not involve the Arduino board itself, the Portenta breakout board was chosen due to its documented and publicly available dimensions. According to the official documentation [3], the high-density connectors J1 and J2 on the breakout board are positioned at 17.14 mm and 60.32 mm, respectively, from the left edge of the PCB. Subtracting these values gives a connector spacing of 43.18 mm, which was then adopted in this design. This specific spacing ensures that the adaptive FPGA board can align with existing motherboard layouts that follow the same connector standard.

This 43.18 mm spacing was manually verified in the PCB layout by placing a dimension line between the connectors using the User.Drawings layer in KiCad. Additionally, the vertical alignment was also verified by ensuring both connectors shared the same Y-axis coordinate. Proper vertical alignment is crucial to avoid pin mismatch or physical stress during insertion into the motherboard.

This evaluation confirms the adaptive capability of the board. Once the FPGA is programmed with the correct bitstream, it can be inserted into the motherboard and immediately recognize and communicate with any connected peripherals via the DF40C connectors. The FPGA is configured to detect the data paths and act accordingly, making the board highly modular and reusable across different applications. The successful alignment of these connectors, along with a clean DRC result, verifies the integrity of the PCB design and validates its use in real-world adaptive embedded systems.

Finally, all electrical connections implemented in both the schematic and PCB layout were carefully designed in accordance with the official datasheets and reference manuals of the electronic components used. This includes the pin mappings, voltage supply lines, decoupling requirements, signal terminations, and communication interfaces. Adherence to component specifications ensures reliable electrical behavior and system stability under real operating conditions. This approach also minimizes the risk of hardware failures during integration with the motherboard and supports the long-term reusability of the adaptive FPGA module across multiple applications.

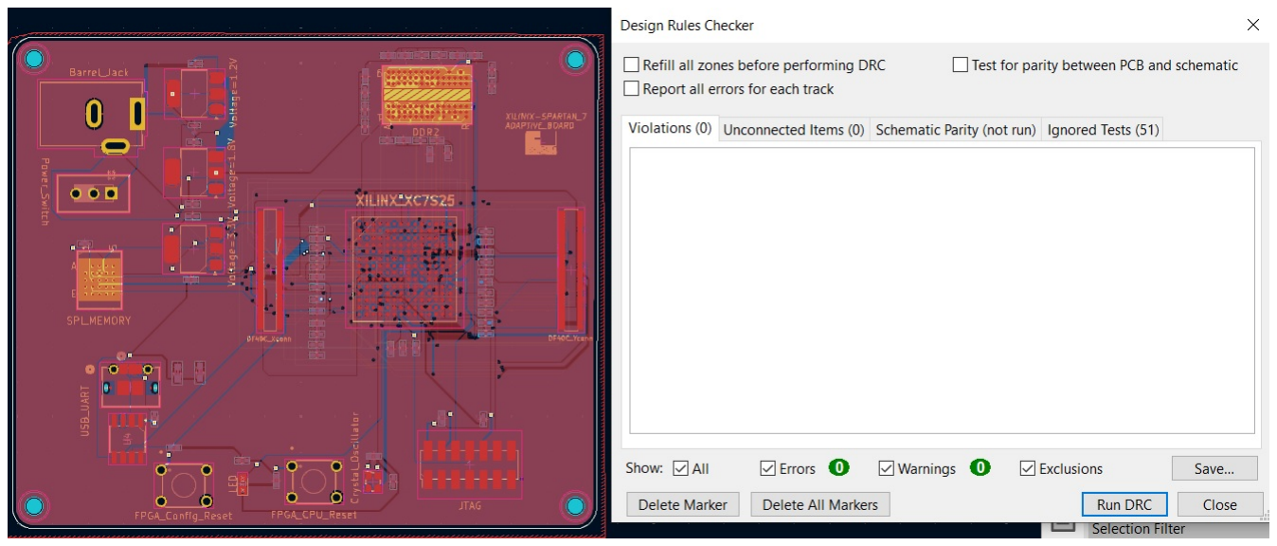
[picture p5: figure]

Figure 9.1: Design Rule Check completed successfully.

C h a p t e r 10

### FUTURE WORK

Although the adaptive FPGA board developed in this project successfully fulfills the functional and mechanical requirements set at the beginning, there remains room for further enhancement and refinement in future iterations. The current design, implemented using a standard 10-layer PCB stack-up, was sufficient to route all required signals and power lines within the constraints of the project. However, a transition to additional layers if high complex system is used so that would significantly improve signal integrity, reduce EMI (electromagnetic interference), and allow for cleaner separation of analog, digital, and power domains. With additional layers, dedicated planes for ground and power (e.g., 3.3V or 1.2V) could be introduced, enabling impedance-controlled routing for high-speed interfaces like SPI and DDR2.

Another area of improvement involves optimizing the placement and routing of high-speed signals. While the current routing strategy respects design rules and functions correctly, differential pair signals or clock lines could benefit from better shielding and tighter impedance matching. This becomes especially relevant in applications where the adaptive board is used in noisy environments or paired with complex peripheral boards.

Mechanically, the DF40C connector alignment is accurate and functional, but future versions of the adaptive board could implement keyed or chamfered edges to simplify insertion and prevent reverse mounting. Additionally, mechanical standoffs or mounting holes could be added to improve structural stability when the board is plugged into a motherboard, particularly in industrial or robotic applications where vibrations are common.

Functionally, one promising future direction is the integration of an onboard non-volatile memory such as a QSPI flash chip. This would allow the FPGA to store and load bitstreams independently without relying on an external programmer or JTAG interface, thereby enabling field reconfiguration and plug-and-play operation. Combined with an embedded MicroBlaze processor, the FPGA could be configured to auto-detect connected peripherals through initialization protocols (e.g., I2C device scanning or GPIO probing) and dynamically adjust its logic configuration at runtime.

Another possible extension is the inclusion of test points or debug headers for easier signal probing and logic analysis during development. While the current board is streamlined and compact, accessibility to key signals would support faster validation, especially during integration with varied motherboards.

Finally, the adaptiveness of the board can be extended further by defining a common interface specification or "adaptive pin map" for all compatible motherboards. This would allow the same FPGA board to be used across a wide variety of carrier boards without requiring logic changes, reinforcing the reusability and scalability of the design. In summary, while the current implementation is functionally and mechanically validated, future iterations can benefit from improvements in signal integrity, mechanical robustness, self-reconfiguration capabilities, and enhanced developer accessibility. These enhancements would not only improve performance and usability but also elevate the board’s value in real-world prototyping and deployment environments.

C h a p t e r 11

### TOOLS AND SOFTWARE USED

The development of the adaptive FPGA board involved the use of several tools and software environments, each contributing to different stages of the design, evaluation, and research process. These tools enabled efficient circuit design, layout optimization, verification, and structured documentation.

The primary tool used for schematic capture and PCB layout was KiCad. KiCad was selected for its powerful yet accessible feature set, support for custom libraries, and compatibility with industry-standard manufacturing formats such as Gerber and drill files. The schematic editor was used to implement the full circuit diagram of the adaptive FPGA board, ensuring proper symbol association, electrical rule checking, and hierarchical block organization. The PCB layout editor enabled the routing of all signal and power traces, placement of the DF40C high-density connectors, and the implementation of DRC (Design Rule Check) rules. The User Drawings layer in KiCad also proved useful in dimensionally verifying connector spacing based on the Arduino Portenta breakout board reference.

In addition, ChatGPT was used to support research throughout the project—particularly in selecting a suitable FPGA model, evaluating communication interface options, and reviewing best practices in embedded system design. It also provided support for technical formatting in LaTeX, assisting in structuring and maintaining consistent style across the report chapters. This made it easier to focus on design and evaluation tasks without spending excess time resolving format-related challenges.

Finally, To manage design files and maintain a clear revision history, Git was used for version control. This ensured that schematic changes, PCB layout adjustments, and LaTeX source files were consistently tracked. Such an approach enhanced project reproducibility, simplified collaboration, and provided a secure backup of all design milestones.

### BIBLIOGRAPHY

[1] Abracon LLC. Standard Clock Oscillators, 2020. Accessed: 2025-06-26.
[2] Analog Devices. Power Management ICs Overview, 2020. Accessed: 2025-06-26.
[3] Arduino AG. Portenta Breakout Board Documentation, 2024. Accessed: 2025-08-04.
[4] P. Athanas and A. M. Jones. A dynamically reconfigurable architecture for adaptive computing. In Proceedings of the IEEE Symposium on FPGAs for Custom Computing Machines, pages 112–119, 1995.
[5] B. Blodget, P. James-Roxby, E. Keller, S. McMillan, and P. Sundararajan. A self-reconfiguring platform. Military and Aerospace Programmable Logic Devices (MAPLD) International Conference, 2003. Review of FPGA use cases in embedded systems.
[6] R. Bogdan and A. Neculoiu. Multilayer pcb design techniques for improved signal integrity. In Proc. IEEE Int. Symp. on Design and Diagnostics of Electronic Circuits and Systems (DDECS), pages 1–4, 2019.
[7] Digilent Inc. Introduction to FPGA Communication Protocols, 2021. Accessed: 2025-06-26.
[8] Digilent Inc. Using LEDs with FPGAs – Reference Guide, 2022. Accessed: 2025-06-26.
[9] M. Gokhale and P. S. Graham. Reconfigurable computing: The theory and practice of fpga-based computation. Springer, 2005.
[10] Hirose Electric Co. Ltd. DF40C Series High-Speed Board-to-Board Connectors, 2021. Accessed: 2025-06-26.
[11] K. Lee. Debounce logic for push buttons on fpga boards. IEEE Circuits and Systems Magazine, 21(4):15–19, 2021.
[12] Silicon Labs. CP210x USB to UART Bridge VCP Drivers, 2020. Accessed: 2025-06-26.
[13] Xilinx Inc. DDR2 Memory Interface Solutions Using Spartan-7 FPGAs, 2022. Accessed: 2025-06-26.
[14] Xilinx Inc. 7 Series FPGAs Data Sheet: Overview (DS180). https://docs.xilinx.com/

v/u/en-US/ds180_7Series_Overview, (https://docs.xilinx.com/v/u/en-US/ds180_7Series_Overview) 2023. Accessed: 2025-05-05.

[15] Xilinx Inc. Spartan-7 FPGA Family. https://www.xilinx.com/products/silicon-

devices/fpga/spartan-7.html, (https://www.xilinx.com/products/silicon-devices/fpga/spartan-7.html) 2023. Accessed: 2025-05-05.

[16] Xilinx Inc. Vivado Design Suite User Guide: Programming and Debugging, 2023. Accessed: 2025-06-26.

### AFFIDAVIT

I, Kashif Raza, herewith declare that I have composed the present paper and work by myself and without use of any other than the cited sources and aids. Sentences or parts of sentences quoted literally are marked as such; other references with regard to the statement and scope are indicated by full details of the publications concerned. The paper and work in the same or similar form has not been submitted to any examination body and has not been published. This paper was not yet, even in part, used in another examination or as a course performance.

Lippstadt, 31 July 2025

Signature

### APPENDIX

This appendix includes all schematic and PCB design images referenced throughout the document. These figures provide a visual representation of the implementation discussed in the corresponding chapters.

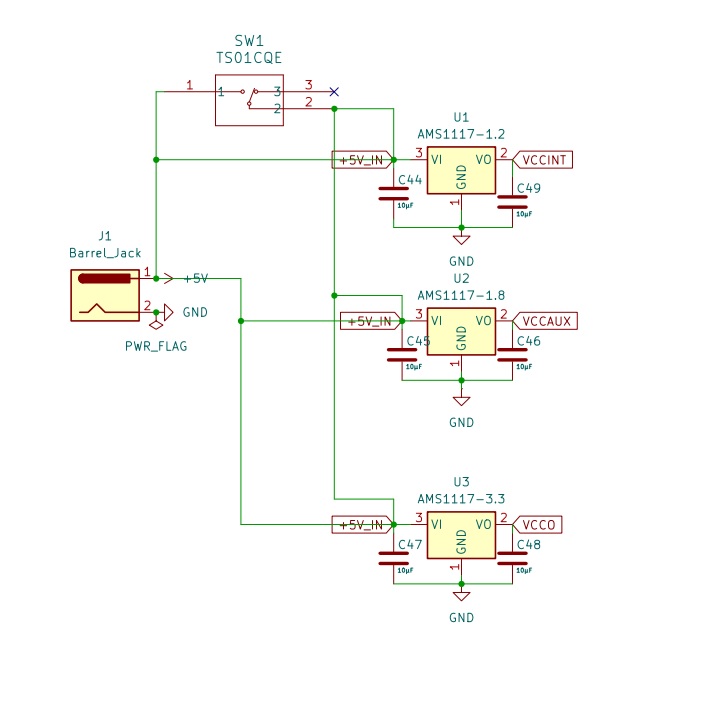
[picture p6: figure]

Figure 8.1: Schematic: Power Management and Voltage Regulation Block

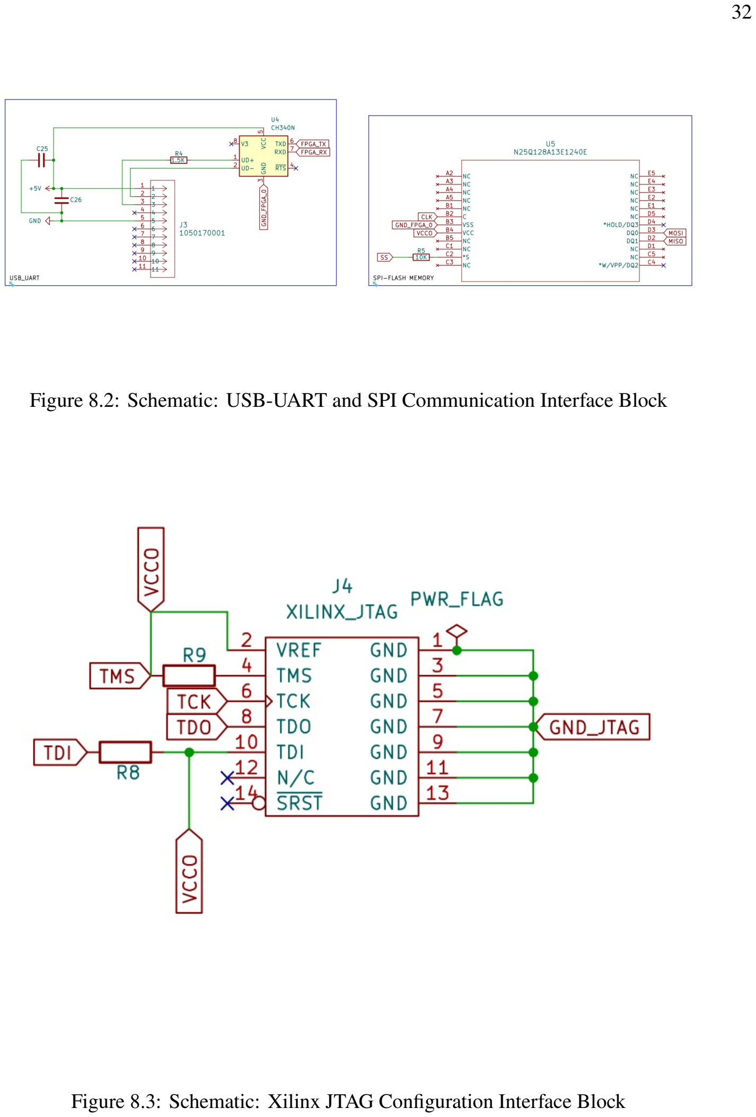
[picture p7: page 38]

Figure 8.2: Schematic: USB-UART and SPI Communication Interface Block

Figure 8.3: Schematic: Xilinx JTAG Configuration Interface Block

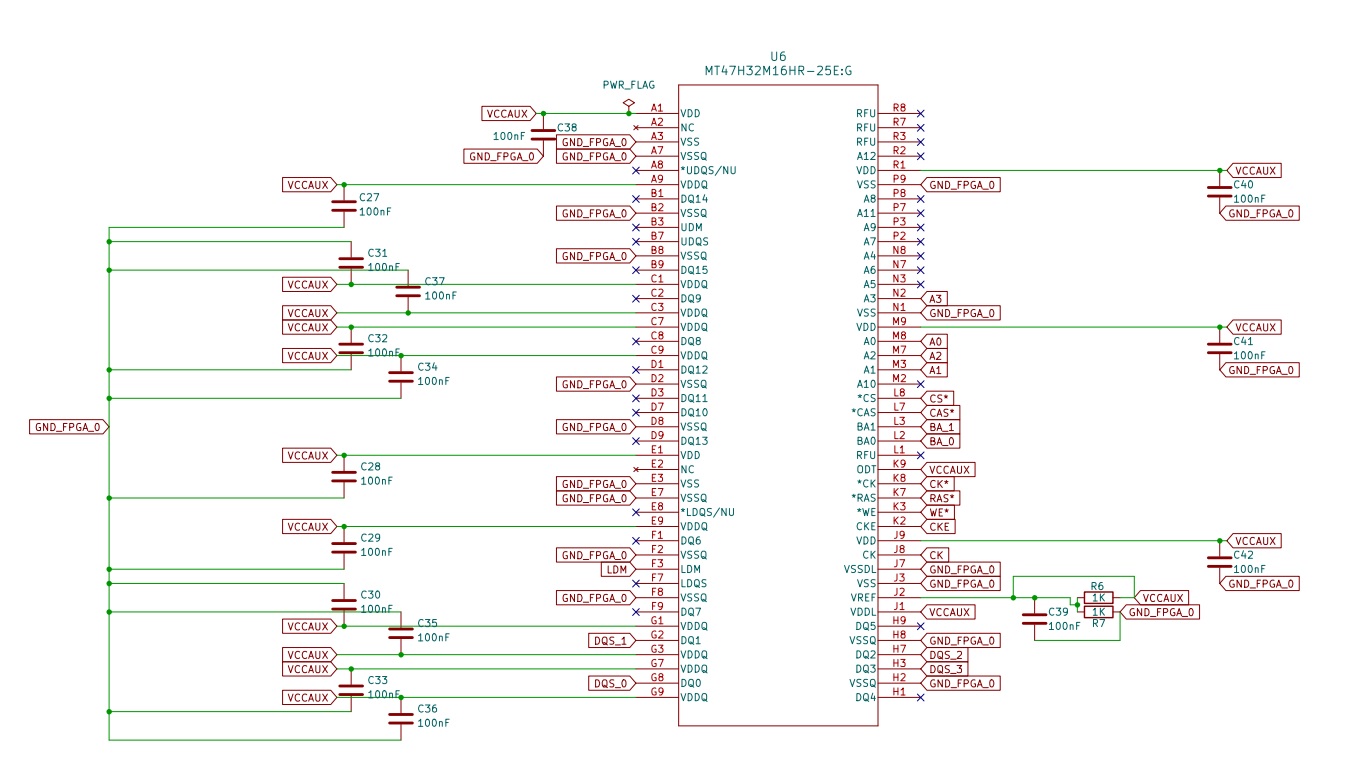
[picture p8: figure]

Figure 8.4: Schematic: External Memory Module Support Block

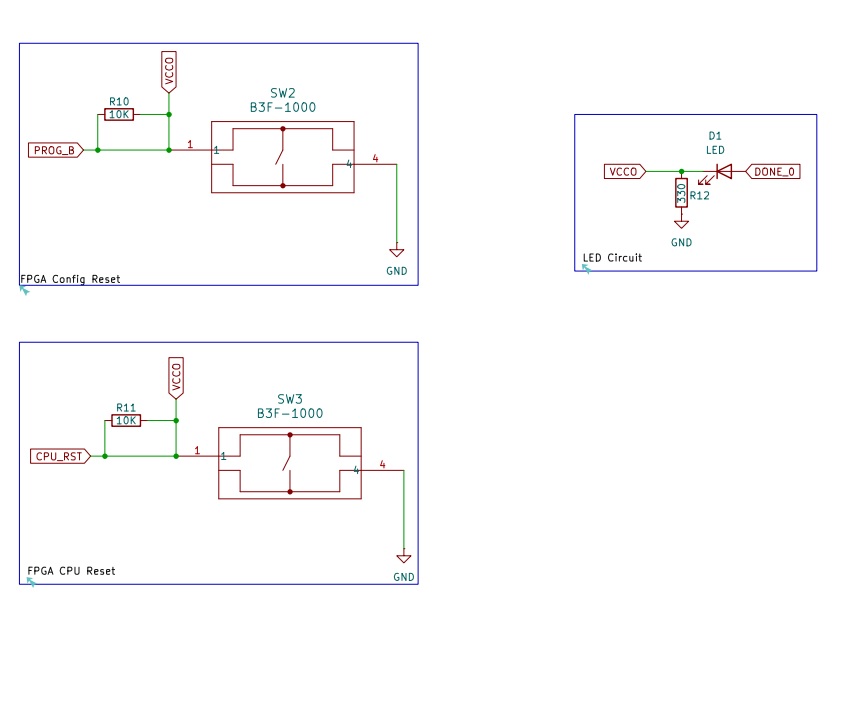
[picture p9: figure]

Figure 8.5: Schematic: Reset and Power LED Indicator Block

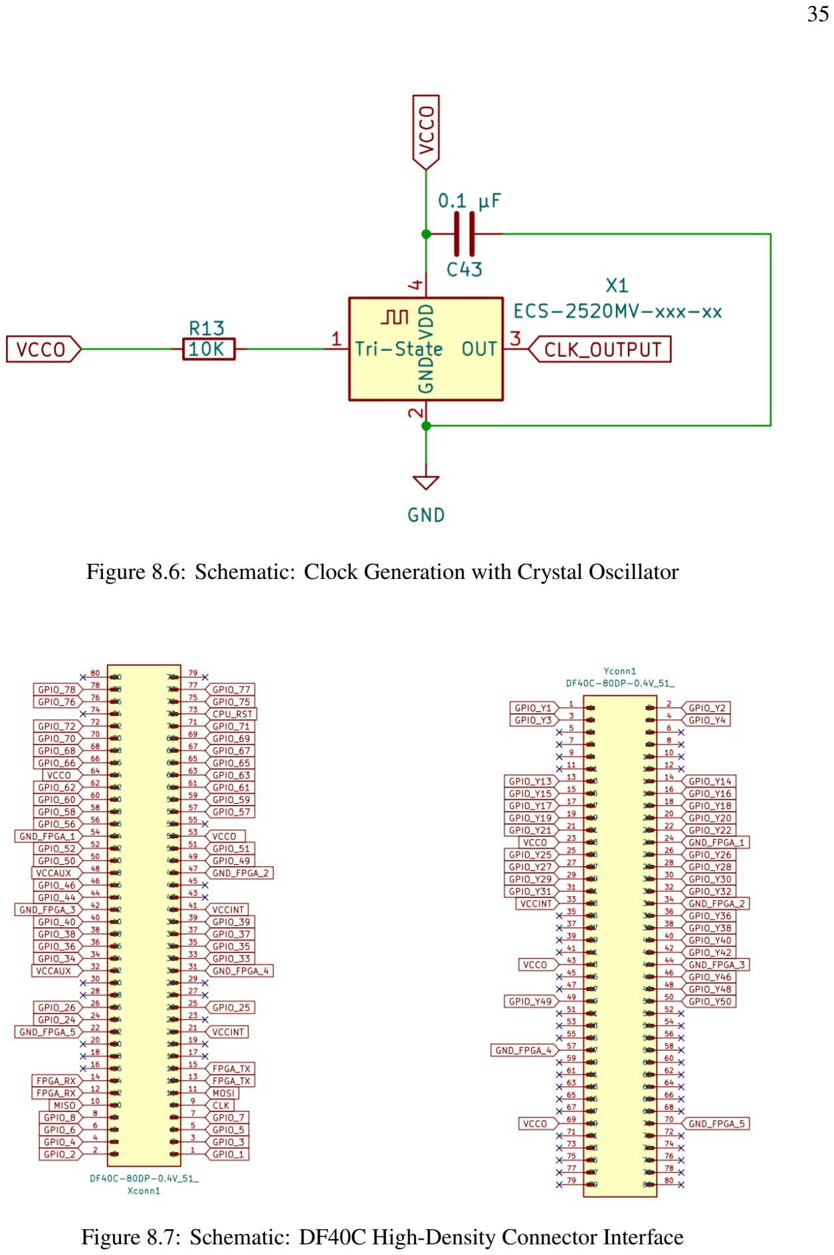
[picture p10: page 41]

Figure 8.6: Schematic: Clock Generation with Crystal Oscillator

Figure 8.7: Schematic: DF40C High-Density Connector Interface

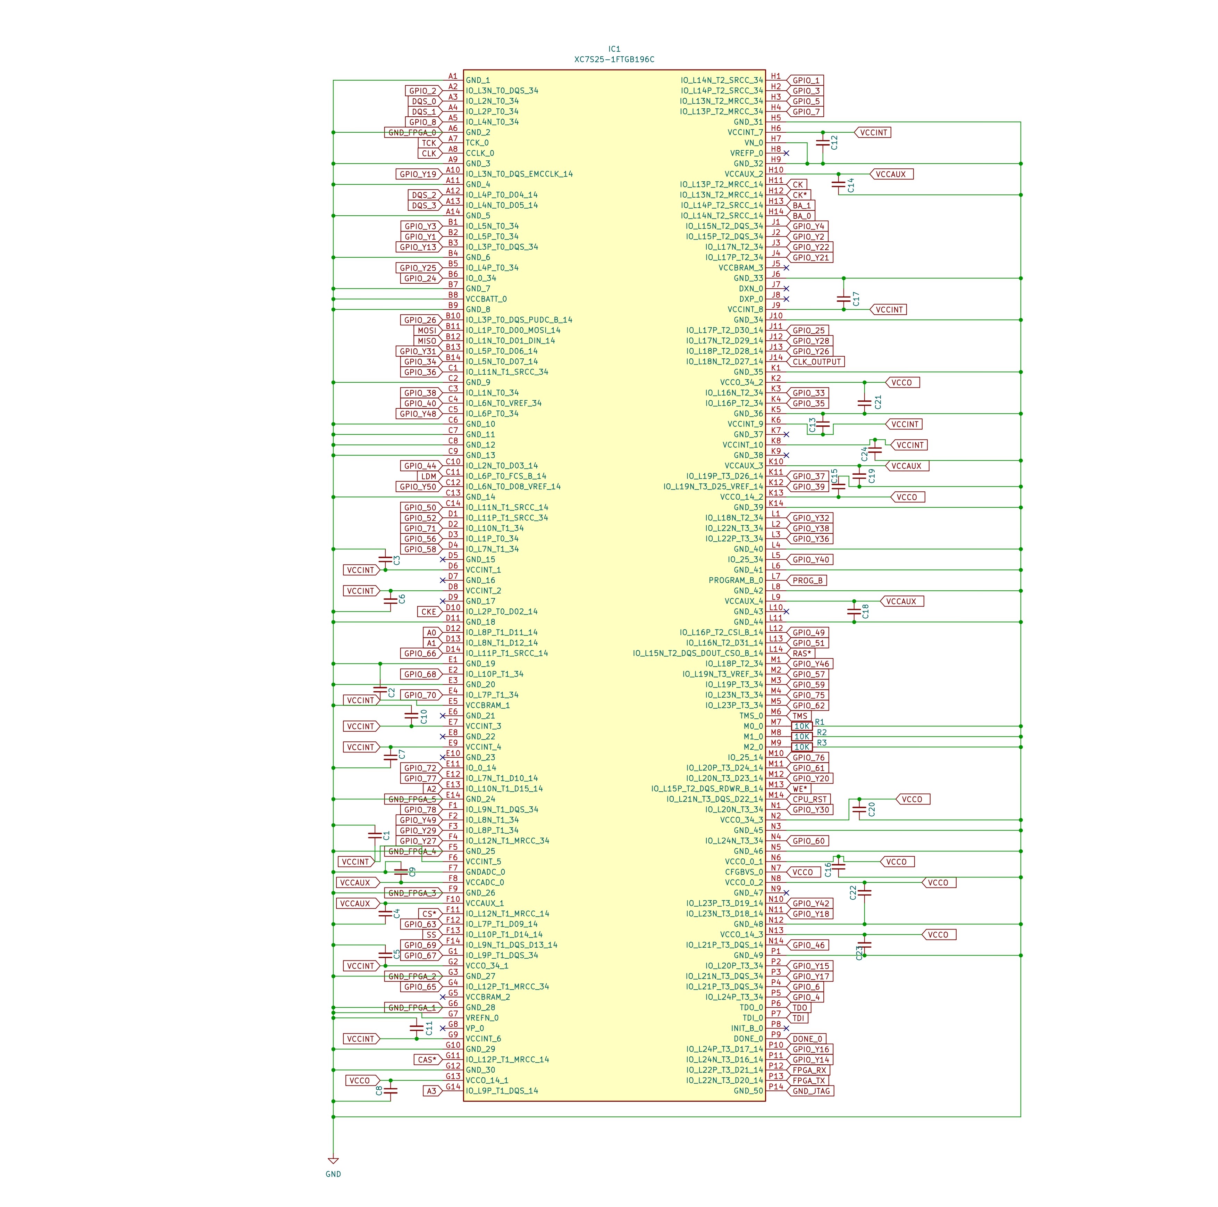
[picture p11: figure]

Figure 8.8: Schematic: Xilinx Spartan-7 FPGA Core Block

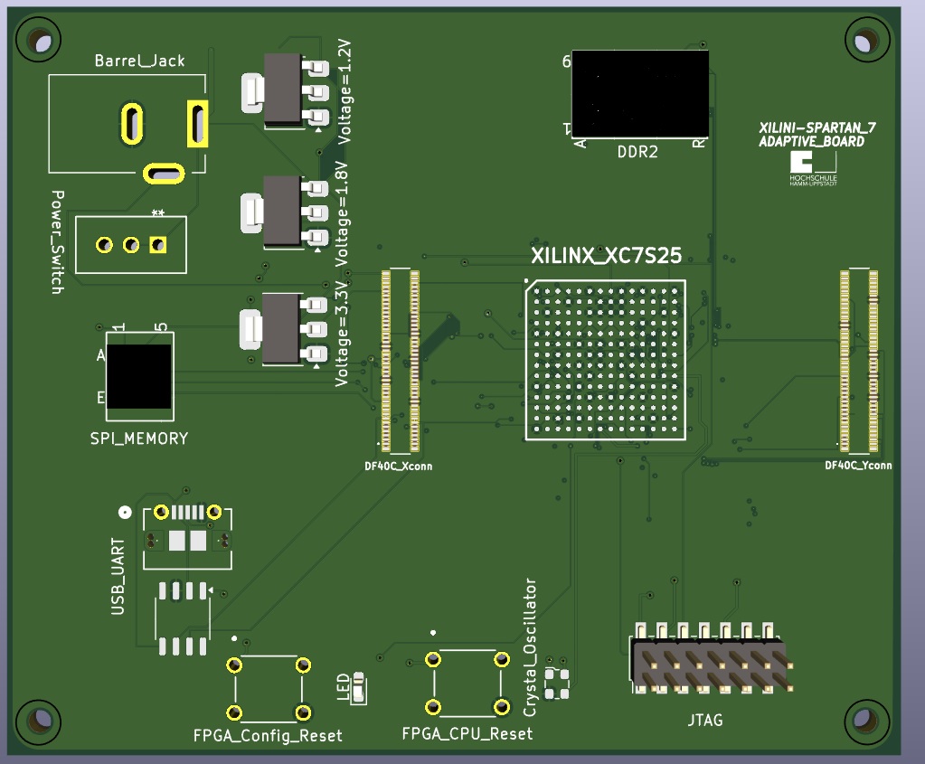
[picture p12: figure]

Figure 8.9: 3D View of Final PCB - Front Side

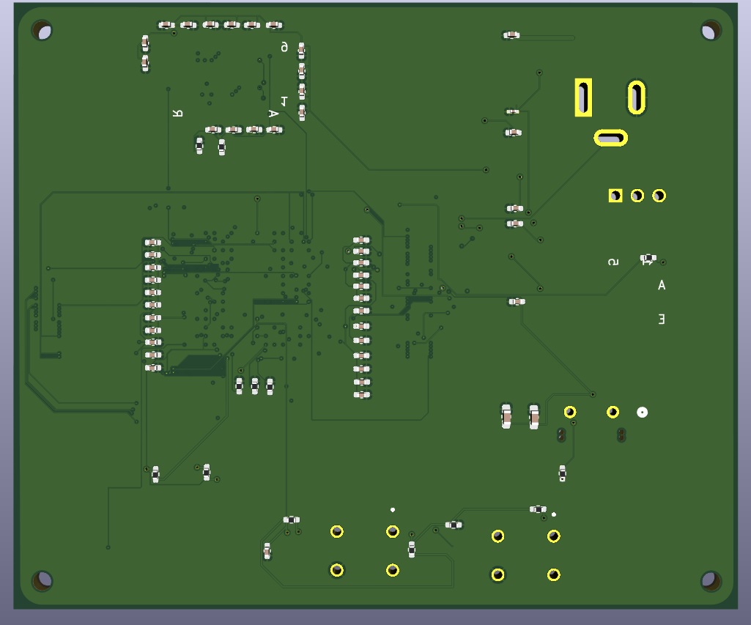
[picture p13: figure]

Figure 8.10: 3D View of Final PCB - Back Side

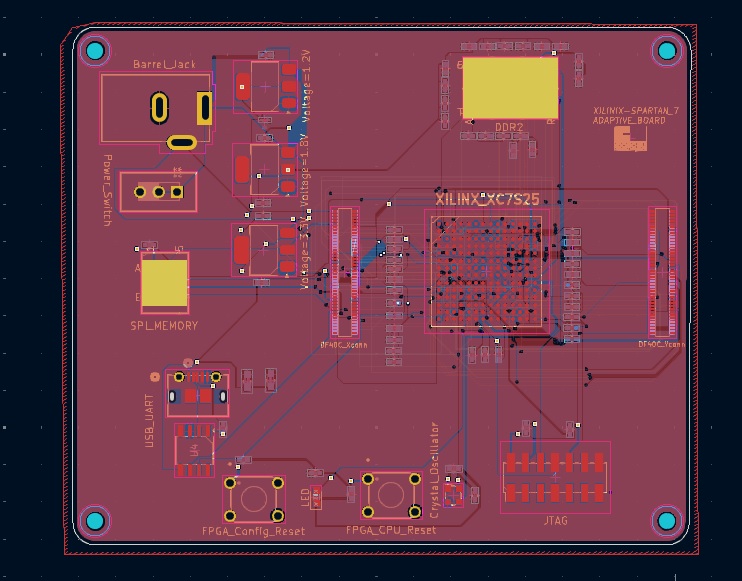
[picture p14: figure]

Figure 8.11: Top View of Final PCB Layout

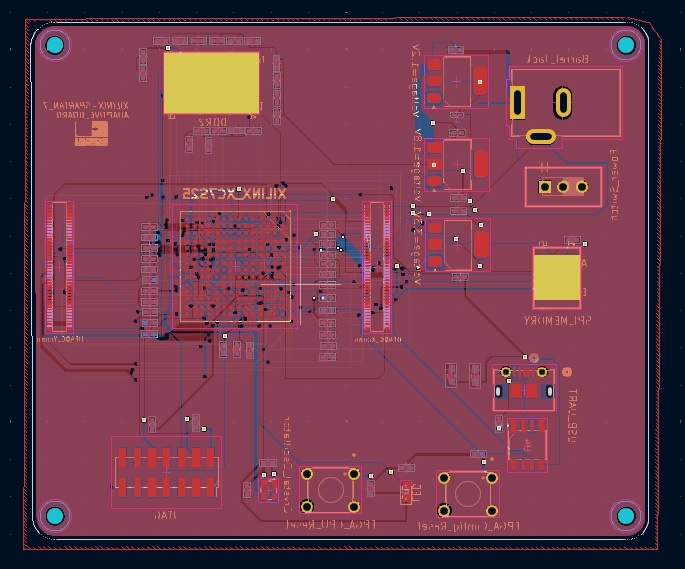
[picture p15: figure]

Figure 8.12: Bottom View of Final PCB Layout

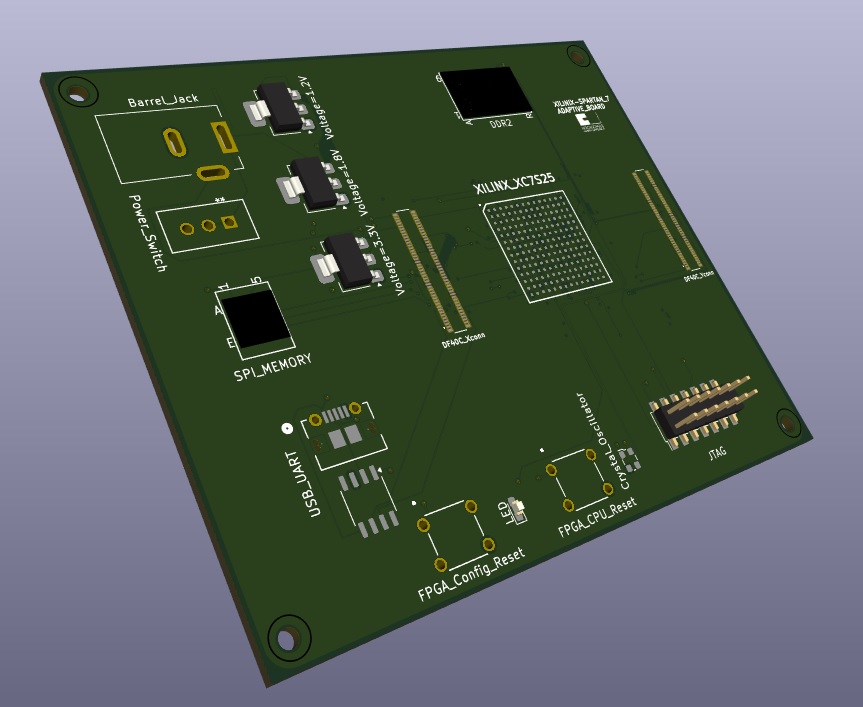
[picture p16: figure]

Figure 8.13: Isometric View of the Assembled Board

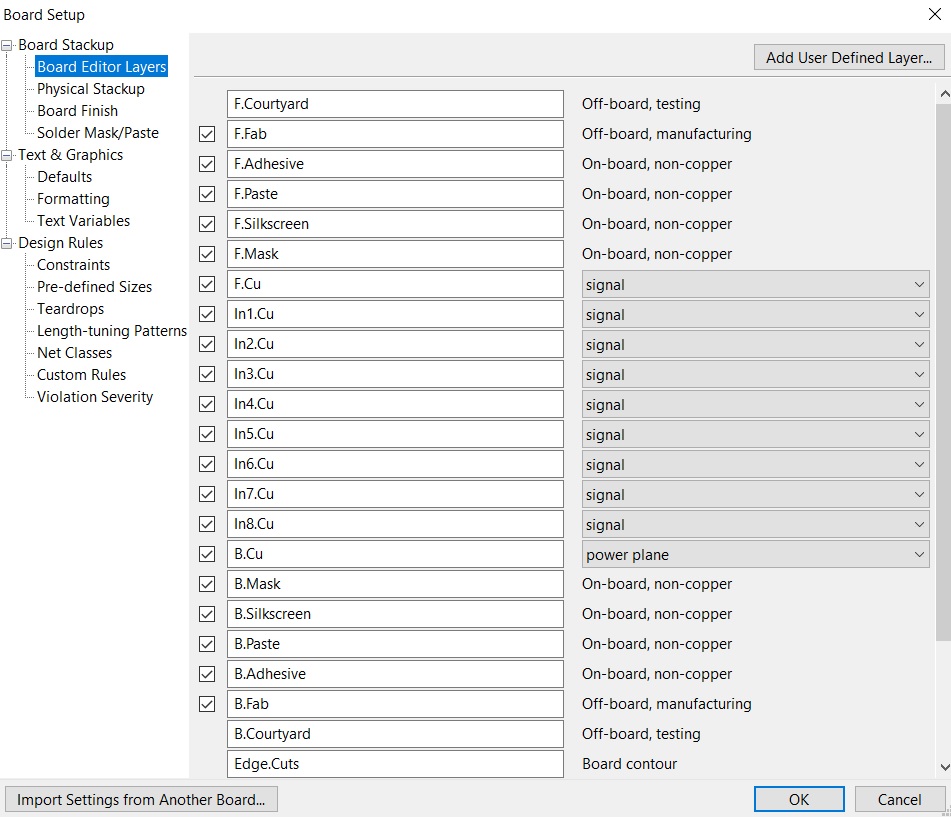
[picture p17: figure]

Figure 8.14: Layer Stackup

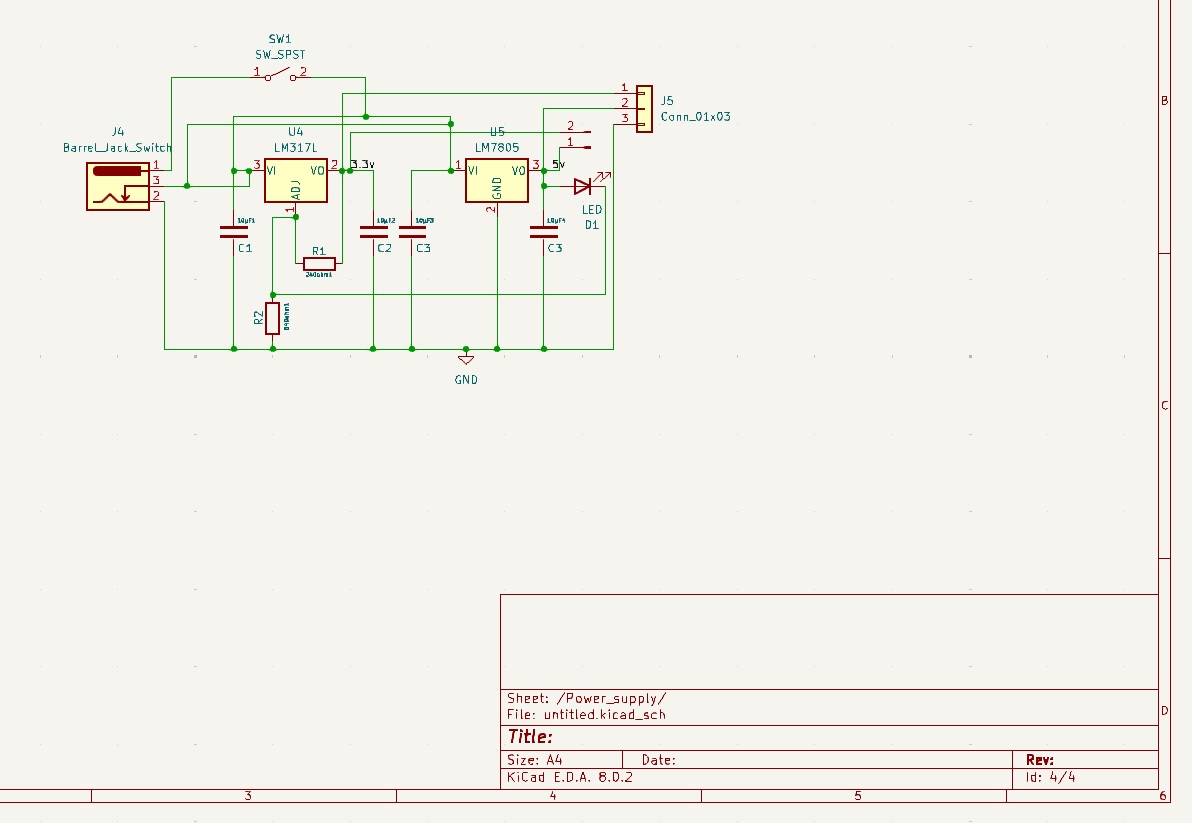
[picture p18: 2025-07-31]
Practice_Works KICAD/Refrence Pictures/FPGA_BOARD SCHEMATIC_02.jpg

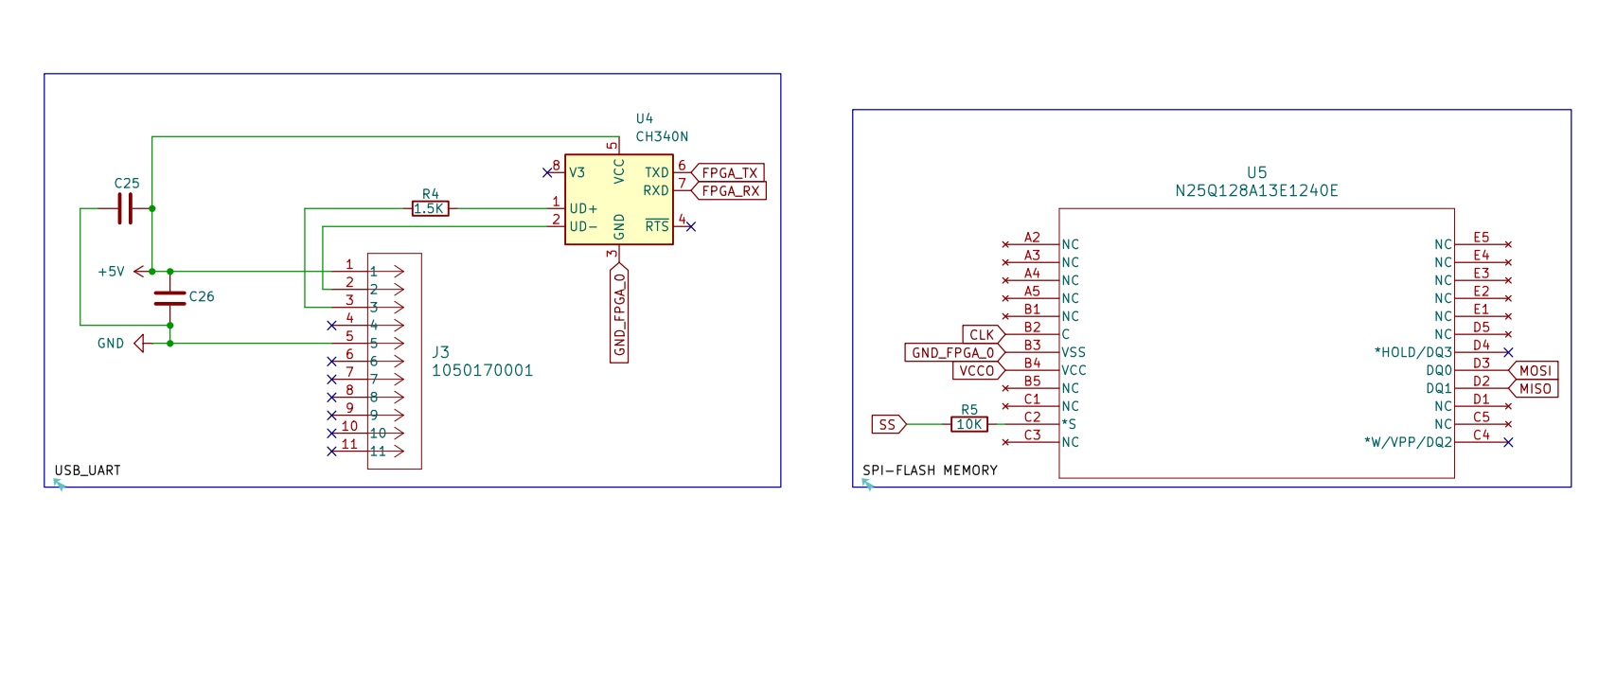
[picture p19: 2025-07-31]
Project_Refrence_Images/Schematics/USB_UART and SPI.jpg

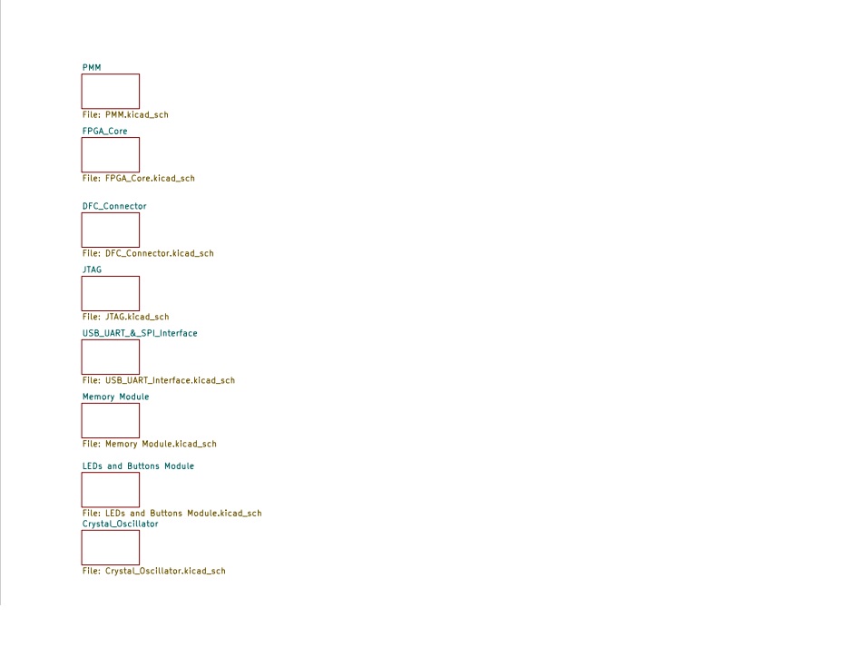
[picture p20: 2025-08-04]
Project_Refrence_Images/Schematics/Schematics_OV.jpg

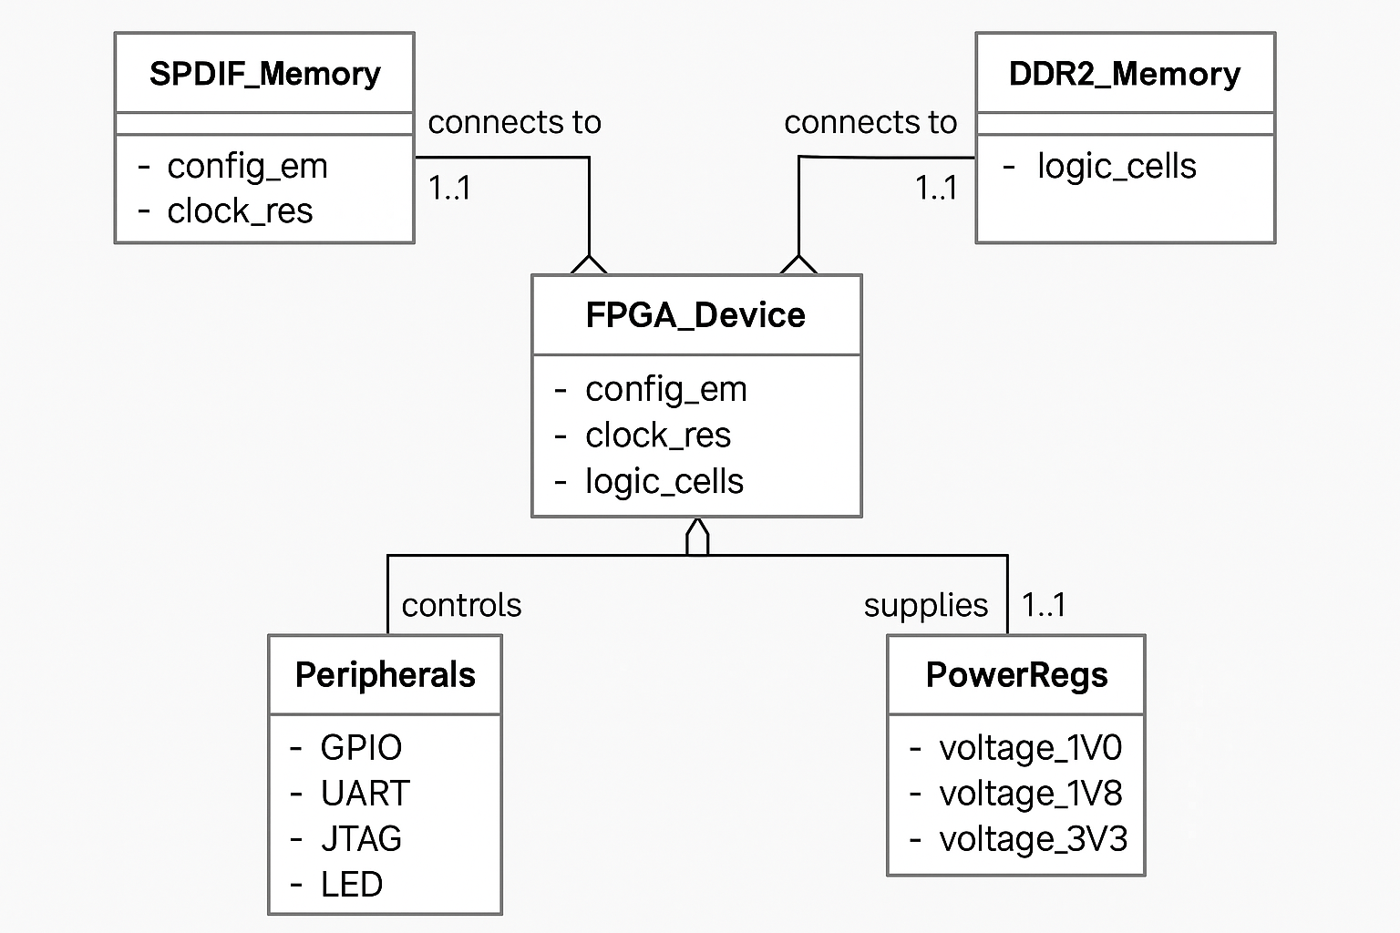
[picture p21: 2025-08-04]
Project_Refrence_Images/Architecture/Block_Diagram0.png

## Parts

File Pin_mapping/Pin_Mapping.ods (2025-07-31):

X-CONN |  |  |  | Y-CONN
Female Connector Pin | Male Connector Pin | Peripheral name | FPGA PIN | Female Connector Pin | Male Connector Pin | Peripheral name | FPGA PIN
X1 | X1 | Keypad R1 | GPIO_1 | Y1 | Y1 | Color sensor S0 | GPIO_Y1
X2 | X2 | Keypad R2 | GPIO_2 | Y2 | Y2 | Moisture sensor signal | GPIO_Y2
X3 | X3 | Keypad R3 | GPIO_3 | Y3 | Y3 | Color sensor S1 | GPIO_Y3
X4 | X4 | Keypad R4 | GPIO_4 | Y4 | Y4 | Color sensor S2 | GPIO_Y4
X5 | X5 | Keypad C1 | GPIO_5 | Y5 | Y5 | GPIO 9 | X
X6 | X6 | Keypad C2 | GPIO_6 | Y6 | Y6 | GPIO 10 | X
X7 | X7 | Keypad C3 | GPIO_7 | Y7 | Y7 | GPIO 11 | X
X8 | X8 | Keypad C4 | GPIO_8 | Y8 | Y8 | GPIO 12 | X
X9 | X9 | SPI SCK | CLK | Y9 | Y9 | GPIO 13 | X
X10 | X10 | SPI MISO | MISO | Y10 | Y10 | GPIO 14 | X
X11 | X11 | SPI MOSI | MOSI | Y11 | Y11 | GPIO 15 | X
X12 | X12 | HC05 BLE RXD | FPGA_RX | Y12 | Y12 | GPIO 16 | X
X13 | X13 | HC05 BLE TXD | FPGA_TX | Y13 | Y13 | Buzzer | GPIO_Y13
X14 | X14 | ESP8266 WLAN RXD | FPGA_RX | Y14 | Y14 | Color sensor S3 | GPIO_Y14
X15 | X15 | ESP8266 WLAN TXD | FPGA_TX | Y15 | Y15 | Seven segment display (segment a) | GPIO_Y15
X16 | X16 | GPIO 1 | X | Y16 | Y16 | Seven segment display (segment b) | GPIO_Y16
X17 | X17 | GPIO 2 | X | Y17 | Y17 | Seven segment display (segment c) | GPIO_Y17
X18 | X18 | GPIO 3 | X | Y18 | Y18 | Seven segment display (segment d) | GPIO_Y18
X19 | X19 | GPIO 4 | X | Y19 | Y19 | Seven segment display (segment e) | GPIO_Y19
X20 | X20 | NC | NC | Y20 | Y20 | Seven segment display (segment f) | GPIO_Y20
X21 | X21 | VIN | VCCINT | Y21 | Y21 | Seven segment display (segment g) | GPIO_Y21
X22 | X22 | GND | GND_FPGA_5 | Y22 | Y22 | Color sensor Out | GPIO_Y22
X23 | X23 | NC | NC | Y23 | Y23 | VCC / +3V3 | VCCO
X24 | X24 | LED 1 | GPIO_24 | Y24 | Y24 | GND | GND_FPGA_1
X25 | X25 | LED 2 | GPIO_25 | Y25 | Y25 | Seven segment display (anode 1) | GPIO_Y25
X26 | X26 | LED 3 | GPIO_26 | Y26 | Y26 | Seven segment display (anode 2) | GPIO_Y26
X27 | X27 | GPIO 5 | X | Y27 | Y27 | Seven segment display (anode 3) | GPIO_Y27
X28 | X28 | GPIO 6 | X | Y28 | Y28 | Seven segment display (anode 4) | GPIO_Y28
X29 | X29 | GPIO 7 | X | Y29 | Y29 | Seven segment display (anode 5) | GPIO_Y29
X30 | X30 | GPIO 8 | X | Y30 | Y30 | Seven segment display (anode 6) | GPIO_Y30
X31 | X31 | GND | GND_FPGA_4 | Y31 | Y31 | Seven segment display (anode 7) | GPIO_Y31
X32 | X32 | VIN | VCCAUX | Y32 | Y32 | Seven segment display (anode 8) | GPIO_Y32
X33 | X33 | LED 4 | GPIO_33 | Y33 | Y33 | GND | GND_FPGA_2
X34 | X34 | LED 5 | GPIO_34 | Y34 | Y34 | VCC | VCCINT
X35 | X35 | LED 6 | GPIO_35 | Y35 | Y35 | NC | NC
X36 | X36 | LED 7 | GPIO_36 | Y36 | Y36 | Motor driver IN2 | GPIO_Y36
X37 | X37 | LED 8 | GPIO_37 | Y37 | Y37 | NC | NC
X38 | X38 | LED 9 | GPIO_38 | Y38 | Y38 | Left IR sensor pin | GPIO_Y38
X39 | X39 | LED 10 | GPIO_39 | Y39 | Y39 | NC | NC
X40 | X40 | LED 11 | GPIO_40 | Y40 | Y40 | Right IR sensor pin | GPIO_Y40
X41 | X41 | VIN | VCCINT | Y41 | Y41 | NC | NC
X42 | X42 | GND | GND_FPGA_3 | Y42 | Y42 | Motor driver IN4 | GPIO_Y42
X43 | X43 | NC | NC | Y43 | Y43 | VCC / +3V3 | VCCO
X44 | X44 | I2C SDA | GPIO_44 | Y44 | Y44 | GND | GND_FPGA_3
X45 | X45 | NC | NC | Y45 | Y45 | NC | NC
X46 | X46 | I2C SCL | GPIO_46 | Y46 | Y46 | PIR motion sensor | GPIO_Y46
X47 | X47 | GND | GND_FPGA_2 | Y47 | Y47 | NC | NC
X48 | X48 | VIN | VCCAUX | Y48 | Y48 | LoRa G0 | GPIO_Y48
X49 | X49 | LED 12 | GPIO_49 | Y49 | Y49 | LoRa CS | GPIO_Y49
X50 | X50 | LED 13 | GPIO_50 | Y50 | Y50 | LoRa RST | GPIO_Y50
X51 | X51 | LED 14 | GPIO_51 | Y51 | Y51 | RFID CS | X
X52 | X52 | LED 15 | GPIO_52 | Y52 | Y52 | RFID RST | X
X53 | X53 | VSYS | VCCO | Y53 | Y53 | NC | NC
X54 | X54 | GND | GND_FPGA_1 | Y54 | Y54 | DHT22 temperature sensor pin | X
X55 | X55 | NC | NC | Y55 | Y55 | NC | NC
X56 | X56 | Switch 1 | GPIO_56 | Y56 | Y56 | NC | NC
X57 | X57 | Switch 2 | GPIO_57 | Y57 | Y57 | GND | GND_FPGA_4
X58 | X58 | Switch 3 | GPIO_58 | Y58 | Y58 | NC | NC
X59 | X59 | Switch 4 | GPIO_59 | Y59 | Y59 | Distance sensor trigger | D6
X60 | X60 | Switch 5 | GPIO_60 | Y60 | Y60 | Motor driver IN1 | D1
X61 | X61 | Switch 6 | GPIO_61 | Y61 | Y61 | Left servo signal | D5
X62 | X62 | Switch 7 | GPIO_62 | Y62 | Y62 | Motor driver EnA | D0
X63 | X63 | Switch 8 | GPIO_63 | Y63 | Y63 | Motor driver IN3 | D4
X64 | X64 | VSYS | VCCO | Y64 | Y64 | NC | NC
X65 | X65 | Switch 9 | GPIO_65 | Y65 | Y65 | Motor driver EnB | D3
X66 | X66 | Switch 10 | GPIO_66 | Y66 | Y66 | NC | NC
X67 | X67 | Switch 11 | GPIO_67 | Y67 | Y67 | Right servo signal | D2
X68 | X68 | Switch 12 | GPIO_68 | Y68 | Y68 | NC | NC
X69 | X69 | Switch 13 | GPIO_69 | Y69 | Y69 | VCC / +3V3 | VCCO
X70 | X70 | Switch 14 | GPIO_70 | Y70 | Y70 | GND | GND_FPGA_5
X71 | X71 | Switch 15 | GPIO_71 | Y71 | Y71 | ADC VREF + | X
X72 | X72 | Switch 16 | GPIO_72 | Y72 | Y72 | ADC VREF - | X
X73 | X73 | RESET | CPU_RST | Y73 | Y73 | LDR | A0
X74 | X74 | NC | NC | Y74 | Y74 | Piezo vibration sensor | A4
X75 | X75 | Push button 1 | GPIO_75 | Y75 | Y75 | Potentiometer 2 | A1
X76 | X76 | Push button 2 | GPIO_76 | Y76 | Y76 | Distance sensor echo | D20
X77 | X77 | Push button 3 | GPIO_77 | Y77 | Y77 | LED 16 | A2
X78 | X78 | Push button 4 | GPIO_78 | Y78 | Y78 | Push button 5 | D21
X79 | X79 | NC | NC | Y79 | Y79 | Microphone analog pin | A3
X80 | X80 | NC | NC | Y80 | Y80 | NC | NC

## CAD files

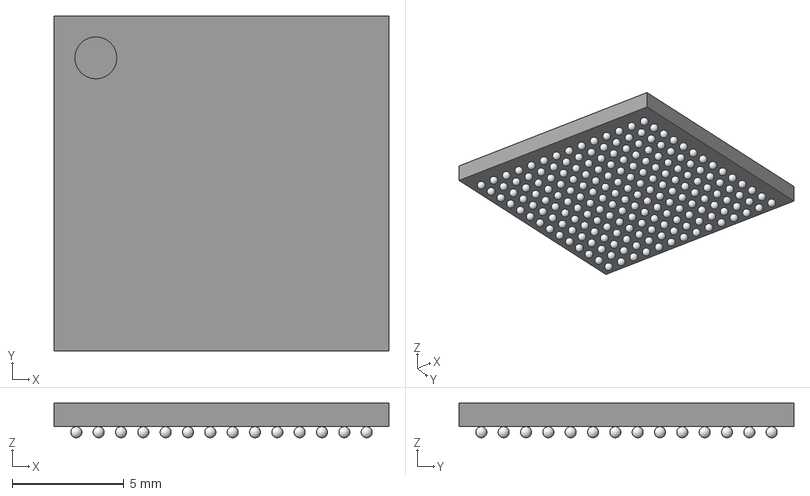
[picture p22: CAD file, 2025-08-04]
KICAD_Files/XC7S25-1FTGB196C/3D/XC7S25-1FTGB196C.stp
15.0 x 15.0 x 1.55 mm

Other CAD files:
KICAD_Files/XC7S25-1FTGB196C/Allegro/bga196c100p14x14_1500x1500x155.psm
KICAD_Files/XC7S25-1FTGB196C/DEHDL/xc7s25_1ftgb196c/chips/chips.prt

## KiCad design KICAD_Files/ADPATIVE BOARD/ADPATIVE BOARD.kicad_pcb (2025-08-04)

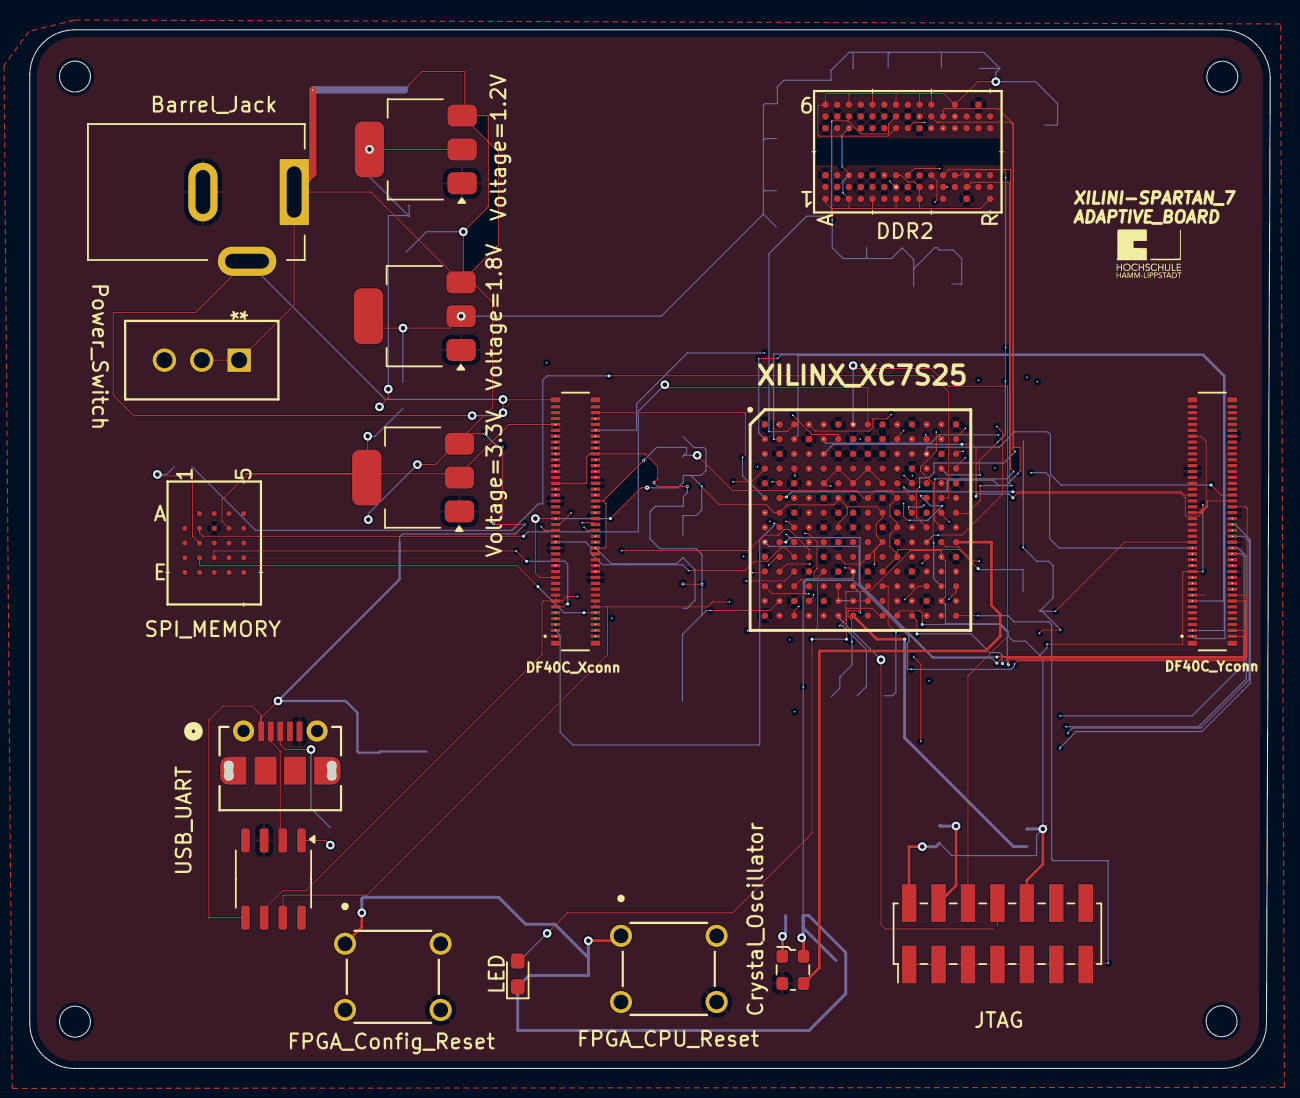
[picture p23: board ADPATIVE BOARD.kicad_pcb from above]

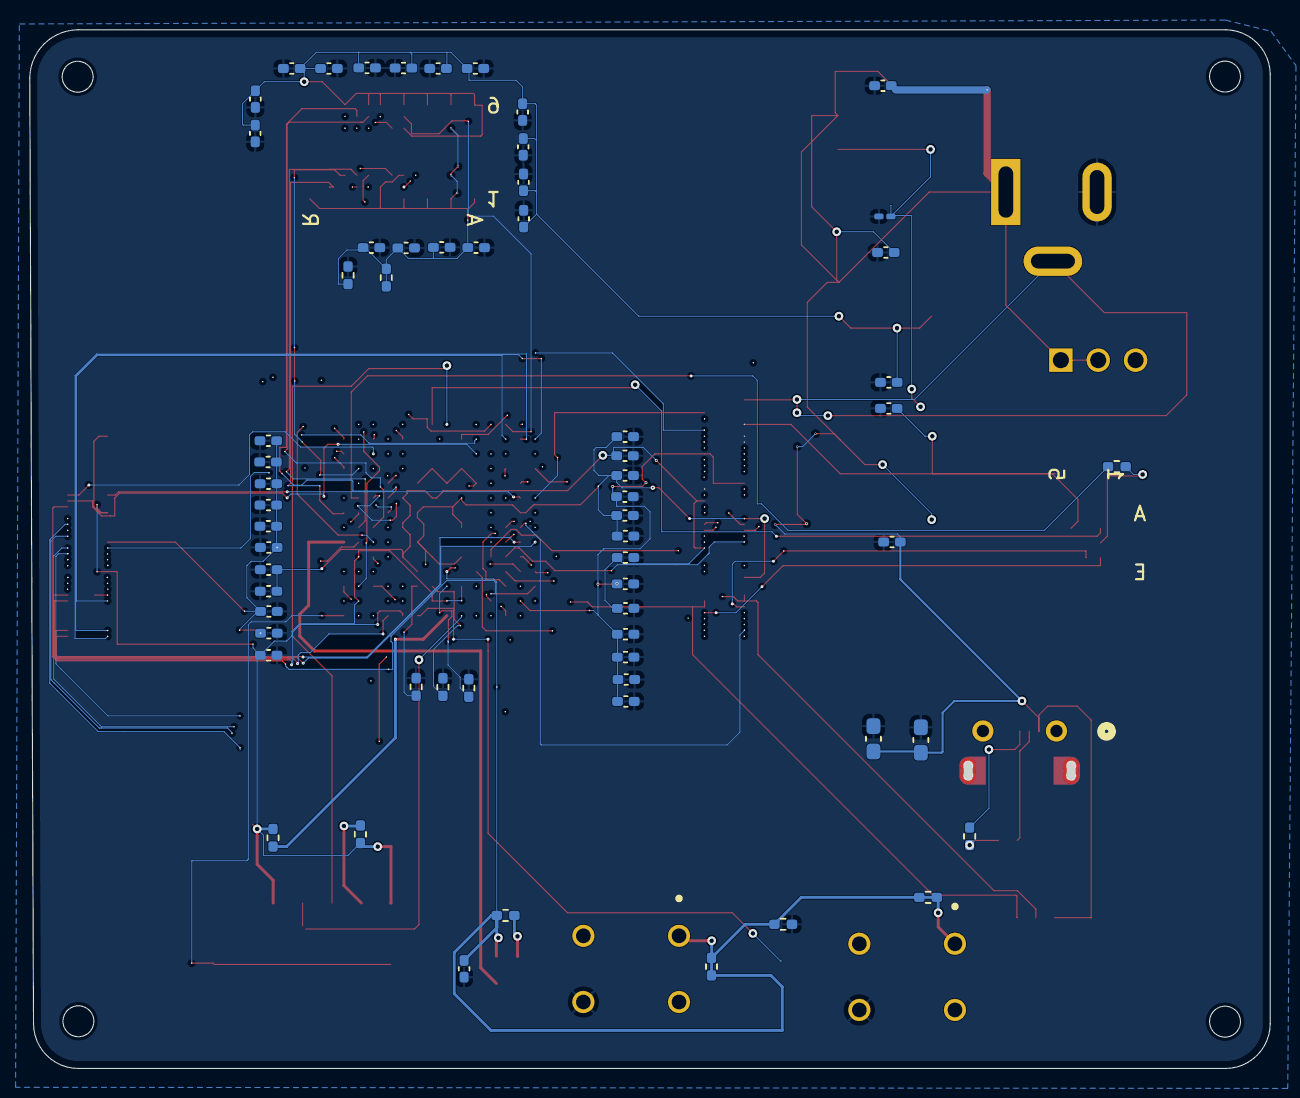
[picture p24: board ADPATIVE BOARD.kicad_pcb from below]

Board: 10 copper layers, 84.3 x 70.6 mm, 79 parts (62 on the bottom side), 118 nets.

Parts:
Barrel_Jack: BarrelJack_Kycon_KLDX-0202-xC_Horizontal
C1, C2, C3, C4, C5, C6, C7, C8, C9, C10, C11, C12, C13, C14, C15, C16, C17, C18, C19, C20, C21, C22, C23, C24: C_0402_1005Metric_Pad0.74x0.62mm_HandSolder
C25, C26: C; C_0603_1608Metric_Pad1.08x0.95mm_HandSolder
C27, C28, C29, C30, C31, C32, C33, C34, C35, C36, C37, C38, C39, C40, C41, C42: 100nF; C_0402_1005Metric_Pad0.74x0.62mm_HandSolder
C43: 0.1 µF; C_0402_1005Metric_Pad0.74x0.62mm_HandSolder
C44, C45, C46, C47, C48: 10µF; C_0402_1005Metric_Pad0.74x0.62mm_HandSolder
C49: 10µF; C_0201_0603Metric_Pad0.64x0.40mm_HandSolder
Crystal_Oscillator: ECS-2520MV-xxx-xx; Oscillator_SMD_ECS_2520MV-xxx-xx-4Pin_2.5x2.0mm
DDR2: MT47H32M16HR-25E:G; FBGA84_8X12P5_MRN
DF40C_Xconn, DF40C_Yconn: DF40C-80DP-0.4V_51_; HRS_DF40C-80DP-0.4V_51_
FPGA_CPU_Reset: B3F-1000; SW_B3F-1000_OMR
FPGA_Config_Reset: B3F-1000; SW_B3F-1000_OMR
JTAG: XILINX_JTAG; PinHeader_2x07_P2.00mm_Vertical_SMD
LED: LED; LED_0603_1608Metric_Pad1.05x0.95mm_HandSolder
Power_Switch: TS01CQE; TS01CQE_CNK
R1, R2, R3, R5, R10, R11, R13: 10K; R_0402_1005Metric_Pad0.72x0.64mm_HandSolder
R4: 1.5K; R_0402_1005Metric_Pad0.72x0.64mm_HandSolder
R6, R7: 1K; R_0402_1005Metric_Pad0.72x0.64mm_HandSolder
R8, R9: R; R_0402_1005Metric_Pad0.72x0.64mm_HandSolder
R12: 330; R_0402_1005Metric_Pad0.72x0.64mm_HandSolder
SPI_MEMORY: N25Q128A13E1240E; MIC-LPBGA-24-12_MRN
U4: CH340N; SOP-8_3.9x4.9mm_P1.27mm
USB_UART: 1050170001; CONN_1050170001_MOL
Voltage=1.2V: AMS1117-1.2; SOT-223-3_TabPin2
Voltage=1.8V: AMS1117-1.8; SOT-223-3_TabPin2
Voltage=3.3V: AMS1117-3.3; SOT-223-3_TabPin2
XILINX_XC7S25: XC7S25-1FTGB196C; BGA196C100P14X14_1500X1500X155

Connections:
+5V_IN: Barrel_Jack.1, C25.2, C26.1, C44.1, C45.1, C47.1, Power_Switch.1, Power_Switch.2, U4.5 (VCC), USB_UART.1, Voltage=1.2V.3 (VI), Voltage=1.8V.3 (VI), Voltage=3.3V.3 (VI)
A0: DDR2.M8 (A0), XILINX_XC7S25.D12 (IO_L8P_T1_D11_14)
A1: DDR2.M3 (A1), XILINX_XC7S25.D13 (IO_L8N_T1_D12_14)
A2: DDR2.M7 (A2), XILINX_XC7S25.E13 (IO_L10N_T1_D15_14)
A3: DDR2.N2 (A3), XILINX_XC7S25.G14 (IO_L9P_T1_DQS_14)
BA_0: DDR2.L2 (BA0), XILINX_XC7S25.H14 (IO_L14N_T2_SRCC_14)
BA_1: DDR2.L3 (BA1), XILINX_XC7S25.H13 (IO_L14P_T2_SRCC_14)
CAS*: DDR2.L7 (*CAS), XILINX_XC7S25.G11 (IO_L12P_T1_MRCC_14)
CK: DDR2.J8 (CK), XILINX_XC7S25.H11 (IO_L13P_T2_MRCC_14)
CK*: DDR2.K8 (*CK), XILINX_XC7S25.H12 (IO_L13N_T2_MRCC_14)
CKE: DDR2.K2 (CKE), XILINX_XC7S25.D10 (IO_L2P_T0_D02_14)
CLK: DF40C_Xconn.9, SPI_MEMORY.B2 (C), XILINX_XC7S25.A8 (CCLK_0)
CLK_OUTPUT: Crystal_Oscillator.3 (OUT), XILINX_XC7S25.J14 (IO_L18N_T2_D27_14)
CPU_RST: C43.1, C48.1, Crystal_Oscillator.4 (VDD), DF40C_Xconn.73, FPGA_CPU_Reset.1, FPGA_Config_Reset.1, LED.1 (K), R10.1, R10.2, R11.1, R11.2, R12.1, R13.1, SPI_MEMORY.B4 (VCC), Voltage=3.3V.2 (VO), XILINX_XC7S25.L7 (PROGRAM_B_0), XILINX_XC7S25.M14 (IO_L21N_T3_DQS_D22_14)
CS*: DDR2.L8 (*CS), XILINX_XC7S25.F11 (IO_L12N_T1_MRCC_14)
DONE_0: LED.2 (A), XILINX_XC7S25.P9 (DONE_0)
DQS_0: DDR2.G8 (DQ0), XILINX_XC7S25.A3 (IO_L2N_T0_34)
DQS_1: DDR2.G2 (DQ1), XILINX_XC7S25.A4 (IO_L2P_T0_34)
DQS_2: DDR2.H7 (DQ2), XILINX_XC7S25.A12 (IO_L4P_T0_D04_14)
DQS_3: DDR2.H3 (DQ3), XILINX_XC7S25.A13 (IO_L4N_T0_D05_14)
FPGA_RX: DF40C_Xconn.12, DF40C_Xconn.14, U4.7 (RXD), XILINX_XC7S25.P12 (IO_L22P_T3_D21_14)
FPGA_TX: DF40C_Xconn.13, DF40C_Xconn.15, U4.6 (TXD), XILINX_XC7S25.P13 (IO_L22N_T3_D20_14)
GND_FPGA_0: Barrel_Jack.2, C1.2, C2.2, C3.2, C4.1, C5.2, C6.1, C7.2, C8.2, C9.2, C10.2, C11.2, C12.2, C13.1, C14.1, C15.2, C16.1, C17.1, C18.2, C19.1, C20.1, C21.1, C22.1, C23.1, C24.2, C25.1, C26.2, C27.2, C28.2, C29.2, C30.1, C31.1, C32.2, C33.2, C34.2, C35.1, C36.2, C37.1, C38.2, C39.2, C40.2, C41.2, C42.2, C43.2, C44.2, C45.2, C46.2, C47.2, C48.2, C49.2, Crystal_Oscillator.2 (GND), DDR2.A3 (VSS), DDR2.A7 (VSSQ), DDR2.B2 (VSSQ), DDR2.B8 (VSSQ), DDR2.D2 (VSSQ), DDR2.D8 (VSSQ), DDR2.E3 (VSS), DDR2.E7 (VSSQ), DDR2.F2 (VSSQ), DDR2.F8 (VSSQ), DDR2.H2 (VSSQ), DDR2.H8 (VSSQ), DDR2.J3 (VSS), DDR2.J7 (VSSDL), DDR2.N1 (VSS), DDR2.P9 (VSS), DF40C_Xconn.22, DF40C_Xconn.31, DF40C_Xconn.42, DF40C_Xconn.47, DF40C_Xconn.54, DF40C_Yconn.24, DF40C_Yconn.34, DF40C_Yconn.44, DF40C_Yconn.57, DF40C_Yconn.70, FPGA_CPU_Reset.4, FPGA_Config_Reset.4, R1.1, R2.1, R3.1, R7.2, R12.2, SPI_MEMORY.B3 (VSS), U4.3 (GND), USB_UART.5, Voltage=1.2V.1 (GND), Voltage=1.8V.1 (GND), Voltage=3.3V.1 (GND), XILINX_XC7S25.A1 (GND_1), XILINX_XC7S25.A6 (GND_2), XILINX_XC7S25.A9 (GND_3), XILINX_XC7S25.A11 (GND_4), XILINX_XC7S25.A14 (GND_5), XILINX_XC7S25.B4 (GND_6), XILINX_XC7S25.B7 (GND_7), XILINX_XC7S25.B8 (VCCBATT_0), XILINX_XC7S25.B9 (GND_8), XILINX_XC7S25.C2 (GND_9), XILINX_XC7S25.C6 (GND_10), XILINX_XC7S25.C7 (GND_11), XILINX_XC7S25.C8 (GND_12), XILINX_XC7S25.C9 (GND_13), XILINX_XC7S25.C13 (GND_14), XILINX_XC7S25.D11 (GND_18), XILINX_XC7S25.E1 (GND_19), XILINX_XC7S25.E3 (GND_20), XILINX_XC7S25.E14 (GND_24), XILINX_XC7S25.F5 (GND_25), XILINX_XC7S25.F7 (GNDADC_0), XILINX_XC7S25.F9 (GND_26), XILINX_XC7S25.G3 (GND_27), XILINX_XC7S25.G6 (GND_28), XILINX_XC7S25.G7 (VREFN_0), XILINX_XC7S25.G10 (GND_29), XILINX_XC7S25.G12 (GND_30), XILINX_XC7S25.H5 (GND_31), XILINX_XC7S25.H7 (VN_0), XILINX_XC7S25.H9 (GND_32), XILINX_XC7S25.J6 (GND_33), XILINX_XC7S25.J10 (GND_34), XILINX_XC7S25.K1 (GND_35), XILINX_XC7S25.K5 (GND_36), XILINX_XC7S25.K14 (GND_39), XILINX_XC7S25.L4 (GND_40), XILINX_XC7S25.L6 (GND_41), XILINX_XC7S25.L8 (GND_42), XILINX_XC7S25.L11 (GND_44), XILINX_XC7S25.N3 (GND_45), XILINX_XC7S25.N5 (GND_46), XILINX_XC7S25.N12 (GND_48), XILINX_XC7S25.P1 (GND_49)
GND_JTAG: JTAG.1 (GND), JTAG.3 (GND), JTAG.5 (GND), JTAG.7 (GND), JTAG.9 (GND), JTAG.11 (GND), JTAG.13 (GND), XILINX_XC7S25.P14 (GND_50)
GPIO_1: DF40C_Xconn.1, XILINX_XC7S25.H1 (IO_L14N_T2_SRCC_34)
GPIO_2: DF40C_Xconn.2, XILINX_XC7S25.A2 (IO_L3N_T0_DQS_34)
GPIO_3: DF40C_Xconn.3, XILINX_XC7S25.H2 (IO_L14P_T2_SRCC_34)
GPIO_4: DF40C_Xconn.4, XILINX_XC7S25.P5 (IO_L24P_T3_34)
GPIO_5: DF40C_Xconn.5, XILINX_XC7S25.H3 (IO_L13N_T2_MRCC_34)
GPIO_6: DF40C_Xconn.6, XILINX_XC7S25.P4 (IO_L21P_T3_DQS_34)
GPIO_7: DF40C_Xconn.7, XILINX_XC7S25.H4 (IO_L13P_T2_MRCC_34)
GPIO_8: DF40C_Xconn.8, XILINX_XC7S25.A5 (IO_L4N_T0_34)
GPIO_24: DF40C_Xconn.24, XILINX_XC7S25.B6 (IO_0_34)
GPIO_25: DF40C_Xconn.25, XILINX_XC7S25.J11 (IO_L17P_T2_D30_14)
GPIO_26: DF40C_Xconn.26, XILINX_XC7S25.B10 (IO_L3P_T0_DQS_PUDC_B_14)
GPIO_33: DF40C_Xconn.33, XILINX_XC7S25.K3 (IO_L16N_T2_34)
GPIO_34: DF40C_Xconn.34, XILINX_XC7S25.B14 (IO_L5N_T0_D07_14)
GPIO_35: DF40C_Xconn.35, XILINX_XC7S25.K4 (IO_L16P_T2_34)
GPIO_36: DF40C_Xconn.36, XILINX_XC7S25.C1 (IO_L11N_T1_SRCC_34)
GPIO_37: DF40C_Xconn.37, XILINX_XC7S25.K11 (IO_L19P_T3_D26_14)
GPIO_38: DF40C_Xconn.38, XILINX_XC7S25.C3 (IO_L1N_T0_34)
GPIO_39: DF40C_Xconn.39, XILINX_XC7S25.K12 (IO_L19N_T3_D25_VREF_14)
GPIO_40: DF40C_Xconn.40, XILINX_XC7S25.C4 (IO_L6N_T0_VREF_34)
GPIO_44: DF40C_Xconn.44, XILINX_XC7S25.C10 (IO_L2N_T0_D03_14)
GPIO_46: DF40C_Xconn.46, XILINX_XC7S25.N14 (IO_L21P_T3_DQS_14)
GPIO_49: DF40C_Xconn.49, XILINX_XC7S25.L12 (IO_L16P_T2_CSI_B_14)
GPIO_50: DF40C_Xconn.50, XILINX_XC7S25.C14 (IO_L11N_T1_SRCC_14)
GPIO_51: DF40C_Xconn.51, XILINX_XC7S25.L13 (IO_L16N_T2_D31_14)
GPIO_52: DF40C_Xconn.52, XILINX_XC7S25.D1 (IO_L11P_T1_SRCC_34)
GPIO_56: DF40C_Xconn.56, XILINX_XC7S25.D3 (IO_L1P_T0_34)
GPIO_57: DF40C_Xconn.57, XILINX_XC7S25.M2 (IO_L19N_T3_VREF_34)
GPIO_58: DF40C_Xconn.58, XILINX_XC7S25.D4 (IO_L7N_T1_34)
GPIO_59: DF40C_Xconn.59, XILINX_XC7S25.M3 (IO_L19P_T3_34)
GPIO_60: DF40C_Xconn.60, XILINX_XC7S25.N4 (IO_L24N_T3_34)
GPIO_61: DF40C_Xconn.61, XILINX_XC7S25.M11 (IO_L20P_T3_D24_14)
GPIO_62: DF40C_Xconn.62, XILINX_XC7S25.M5 (IO_L23P_T3_34)
GPIO_63: DF40C_Xconn.63, XILINX_XC7S25.F12 (IO_L7P_T1_D09_14)
GPIO_65: DF40C_Xconn.65, XILINX_XC7S25.G4 (IO_L12P_T1_MRCC_34)
GPIO_66: DF40C_Xconn.66, XILINX_XC7S25.D14 (IO_L11P_T1_SRCC_14)
GPIO_67: DF40C_Xconn.67, XILINX_XC7S25.G1 (IO_L9P_T1_DQS_34)
GPIO_68: DF40C_Xconn.68, XILINX_XC7S25.E2 (IO_L10P_T1_34)
GPIO_69: DF40C_Xconn.69, XILINX_XC7S25.F14 (IO_L9N_T1_DQS_D13_14)
GPIO_70: DF40C_Xconn.70, XILINX_XC7S25.E4 (IO_L7P_T1_34)
GPIO_72: DF40C_Xconn.72, XILINX_XC7S25.E11 (IO_0_14)
GPIO_76: DF40C_Xconn.76, XILINX_XC7S25.M10 (IO_25_14)
GPIO_78: DF40C_Xconn.78, XILINX_XC7S25.F1 (IO_L9N_T1_DQS_34)
GPIO_Y1: DF40C_Yconn.1, XILINX_XC7S25.B2 (IO_L5P_T0_34)
GPIO_Y2: DF40C_Yconn.2, XILINX_XC7S25.J2 (IO_L15P_T2_DQS_34)
GPIO_Y3: DF40C_Yconn.3, XILINX_XC7S25.B1 (IO_L5N_T0_34)
GPIO_Y4: DF40C_Yconn.4, XILINX_XC7S25.J1 (IO_L15N_T2_DQS_34)
GPIO_Y13: DF40C_Yconn.13, XILINX_XC7S25.B3 (IO_L3P_T0_DQS_34)
GPIO_Y14: DF40C_Yconn.14, XILINX_XC7S25.P11 (IO_L24N_T3_D16_14)
GPIO_Y15: DF40C_Yconn.15, XILINX_XC7S25.P2 (IO_L20P_T3_34)
GPIO_Y16: DF40C_Yconn.16, XILINX_XC7S25.P10 (IO_L24P_T3_D17_14)
GPIO_Y17: DF40C_Yconn.17, XILINX_XC7S25.P3 (IO_L21N_T3_DQS_34)
GPIO_Y18: DF40C_Yconn.18, XILINX_XC7S25.N11 (IO_L23N_T3_D18_14)
GPIO_Y19: DF40C_Yconn.19, XILINX_XC7S25.A10 (IO_L3N_T0_DQS_EMCCLK_14)
GPIO_Y20: DF40C_Yconn.20, XILINX_XC7S25.M12 (IO_L20N_T3_D23_14)
GPIO_Y21: DF40C_Yconn.21, XILINX_XC7S25.J4 (IO_L17P_T2_34)
GPIO_Y22: DF40C_Yconn.22, XILINX_XC7S25.J3 (IO_L17N_T2_34)
GPIO_Y25: DF40C_Yconn.25, XILINX_XC7S25.B5 (IO_L4P_T0_34)
GPIO_Y26: DF40C_Yconn.26, XILINX_XC7S25.J13 (IO_L18P_T2_D28_14)
GPIO_Y27: DF40C_Yconn.27, XILINX_XC7S25.F4 (IO_L12N_T1_MRCC_34)
GPIO_Y28: DF40C_Yconn.28, XILINX_XC7S25.J12 (IO_L17N_T2_D29_14)
GPIO_Y29: DF40C_Yconn.29, XILINX_XC7S25.F3 (IO_L8P_T1_34)
GPIO_Y30: DF40C_Yconn.30, XILINX_XC7S25.N1 (IO_L20N_T3_34)
GPIO_Y31: DF40C_Yconn.31, XILINX_XC7S25.B13 (IO_L5P_T0_D06_14)
GPIO_Y32: DF40C_Yconn.32, XILINX_XC7S25.L1 (IO_L18N_T2_34)
GPIO_Y36: DF40C_Yconn.36, XILINX_XC7S25.L3 (IO_L22P_T3_34)
GPIO_Y38: DF40C_Yconn.38, XILINX_XC7S25.L2 (IO_L22N_T3_34)
GPIO_Y40: DF40C_Yconn.40, XILINX_XC7S25.L5 (IO_25_34)
GPIO_Y42: DF40C_Yconn.42, XILINX_XC7S25.N10 (IO_L23P_T3_D19_14)
GPIO_Y46: DF40C_Yconn.46, XILINX_XC7S25.M1 (IO_L18P_T2_34)
GPIO_Y48: DF40C_Yconn.48, XILINX_XC7S25.C5 (IO_L6P_T0_34)
GPIO_Y49: DF40C_Yconn.49, XILINX_XC7S25.F2 (IO_L8N_T1_34)
GPIO_Y50: DF40C_Yconn.50, XILINX_XC7S25.C12 (IO_L6N_T0_D08_VREF_14)
LDM: DDR2.F3 (LDM), XILINX_XC7S25.C11 (IO_L6P_T0_FCS_B_14)
MISO: DF40C_Xconn.10, SPI_MEMORY.D2 (DQ1), XILINX_XC7S25.B12 (IO_L1N_T0_D01_DIN_14)
MOSI: DF40C_Xconn.11, SPI_MEMORY.D3 (DQ0), XILINX_XC7S25.B11 (IO_L1P_T0_D00_MOSI_14)
unnamed: R1.2, XILINX_XC7S25.M7 (M0_0)
unnamed: R2.2, XILINX_XC7S25.M8 (M1_0)
unnamed: R3.2, XILINX_XC7S25.M9 (M2_0)
unnamed: R4.2, USB_UART.3
unnamed: JTAG.4 (TMS), R9.1
unnamed: R4.1, U4.1 (UD+)
unnamed: U4.2 (UD-), USB_UART.2
unnamed: R5.2, SPI_MEMORY.C2 (*S)
unnamed: Crystal_Oscillator.1 (Tri-State), R13.2
RAS*: DDR2.K7 (*RAS), XILINX_XC7S25.L14 (IO_L15N_T2_DQS_DOUT_CSO_B_14)
SS: R5.1, XILINX_XC7S25.F13 (IO_L10P_T1_D14_14)
TCK: JTAG.6 (TCK), XILINX_XC7S25.A7 (TCK_0)
TDI: R8.2, XILINX_XC7S25.P7 (TDI_0)
TDO: JTAG.8 (TDO), XILINX_XC7S25.P6 (TDO_0)
TMS: C8.1, C15.1, C16.2, C20.2, C21.2, C22.2, C23.2, DF40C_Xconn.53, DF40C_Xconn.64, DF40C_Yconn.23, DF40C_Yconn.43, DF40C_Yconn.69, JTAG.2 (VREF), JTAG.10 (TDI), R8.1, R9.2, XILINX_XC7S25.G13 (VCCO_14_1), XILINX_XC7S25.K2 (VCCO_34_2), XILINX_XC7S25.K13 (VCCO_14_2), XILINX_XC7S25.M6 (TMS_0), XILINX_XC7S25.N2 (VCCO_34_3), XILINX_XC7S25.N6 (VCCO_0_1), XILINX_XC7S25.N7 (CFGBVS_0), XILINX_XC7S25.N8 (VCCO_0_2), XILINX_XC7S25.N13 (VCCO_14_3)
VCCAUX: C27.1, C28.1, C29.1, C30.2, C31.2, C32.1, C33.1, C34.1, C35.2, C36.1, C37.2, C38.1, C39.1, C40.1, C41.1, C42.1, C46.1, DDR2.A1 (VDD), DDR2.A9 (VDDQ), DDR2.C1 (VDDQ), DDR2.C3 (VDDQ), DDR2.C7 (VDDQ), DDR2.C9 (VDDQ), DDR2.E1 (VDD), DDR2.E9 (VDDQ), DDR2.G1 (VDDQ), DDR2.G3 (VDDQ), DDR2.G7 (VDDQ), DDR2.G9 (VDDQ), DDR2.J1 (VDDL), DDR2.J2 (VREF), DDR2.J9 (VDD), DDR2.K9 (ODT), DDR2.M9 (VDD), DDR2.R1 (VDD), R6.1, R6.2, R7.1, Voltage=1.8V.2 (VO)
VCCAUX: C4.2, C9.1, C14.2, C18.1, C19.2, DF40C_Xconn.32, DF40C_Xconn.48, XILINX_XC7S25.F8 (VCCADC_0), XILINX_XC7S25.F10 (VCCAUX_1), XILINX_XC7S25.H10 (VCCAUX_2), XILINX_XC7S25.K10 (VCCAUX_3), XILINX_XC7S25.L9 (VCCAUX_4)
VCCINT: C1.1, C2.1, C3.1, C5.1, C6.2, C7.1, C10.1, C11.1, C12.1, C13.2, C17.2, C24.1, C49.1, DF40C_Xconn.21, DF40C_Xconn.41, DF40C_Yconn.33, Voltage=1.2V.2 (VO), XILINX_XC7S25.D6 (VCCINT_1), XILINX_XC7S25.D8 (VCCINT_2), XILINX_XC7S25.E5 (VCCBRAM_1), XILINX_XC7S25.E7 (VCCINT_3), XILINX_XC7S25.E9 (VCCINT_4), XILINX_XC7S25.F6 (VCCINT_5), XILINX_XC7S25.G2 (VCCO_34_1), XILINX_XC7S25.G9 (VCCINT_6), XILINX_XC7S25.H6 (VCCINT_7), XILINX_XC7S25.J9 (VCCINT_8), XILINX_XC7S25.K6 (VCCINT_9), XILINX_XC7S25.K8 (VCCINT_10)
WE*: DDR2.K3 (*WE), XILINX_XC7S25.M13 (IO_L15P_T2_DQS_RDWR_B_14)

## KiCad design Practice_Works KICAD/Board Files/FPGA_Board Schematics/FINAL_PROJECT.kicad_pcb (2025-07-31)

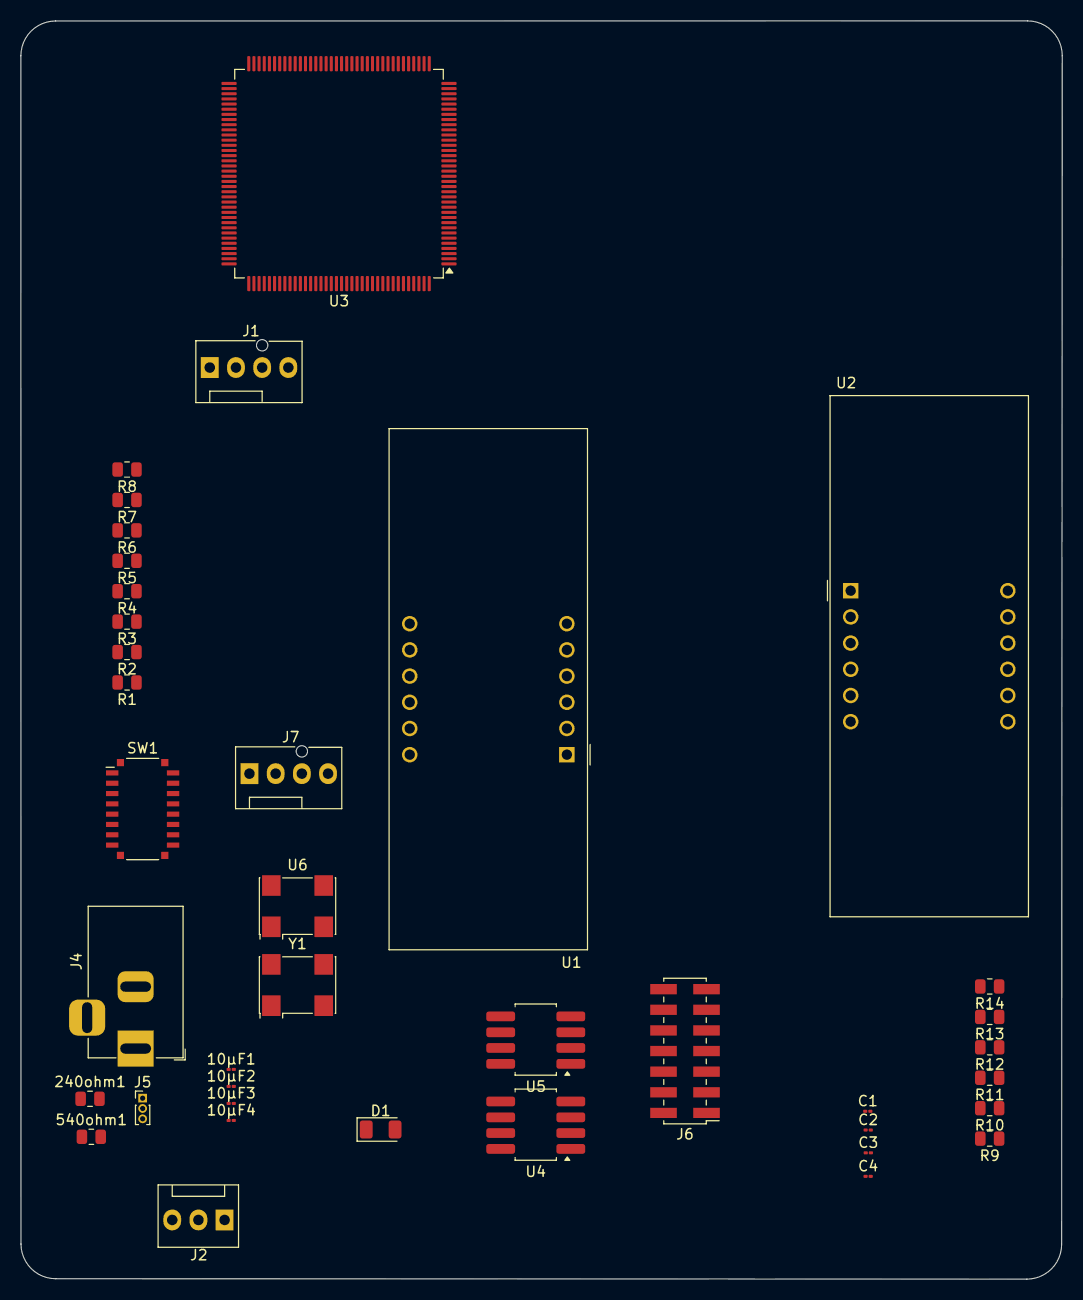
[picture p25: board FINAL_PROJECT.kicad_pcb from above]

Board: 2 copper layers, 101.0 x 122.0 mm, 39 parts (0 on the bottom side), 39 nets, no tracks yet.

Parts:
10µF1: C1; C_01005_0402Metric
10µF2: C2; C_01005_0402Metric
10µF3, 10µF4: C3; C_01005_0402Metric
240ohm1: R1; R_0805_2012Metric
540ohm1: R2; R_0805_2012Metric
C1, C2, C3, C4: C; C_01005_0402Metric
D1: LED; LED_1206_3216Metric
J1, J7: Conn_01x06_Pin; FanPinHeader_1x04_P2.54mm_Vertical
J2: Conn_01x02_Pin; FanPinHeader_1x03_P2.54mm_Vertical
J4: Barrel_Jack_Switch; BarrelJack_Horizontal
J5: Conn_01x03; PinHeader_1x03_P1.00mm_Vertical
J6: XILINX_JTAG; PinHeader_2x07_P2.00mm_Vertical_SMD
R1, R2, R3, R4, R5, R6, R7, R8, R10, R11, R12, R13, R14: R; R_0805_2012Metric
R9: 10k; R_0805_2012Metric
SW1: SW_SPST; SW_DIP_SPSTx08_Slide_Copal_CVS-08xB_W5.9mm_P1mm
U1, U2: CA56-12CGKWA
U3: LFXP2-5E-5TN144; TQFP-144_20x20mm_P0.5mm
U4: LM317L; SOT-223-8
U5: LM7805; SOT-223-8
U6: Oscillator_SMD_Abracon_ASV-4Pin_7.0x5.1mm
Y1: Oscillator; Oscillator_SMD_Abracon_ASV-4Pin_7.0x5.1mm

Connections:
+3.3V: C1.1, C2.1, C3.1, C4.1, J6.2 (VREF), R9.1, R10.1, R11.2, R12.2, R13.2, R14.2, U6.1 (VCCADC), Y1.1, Y1.2
/powersupply/3.3v: 10µF2.1, 240ohm1.2, J2.2, J5.1, U4.2 (VO)
/powersupply/5v: 10µF4.1, D1.2 (A), J2.1, J5.2, U5.3 (VO)
GND: 10µF1.2, 10µF2.2, 10µF3.2, 10µF4.2, 540ohm1.1, C1.2, C2.2, C3.2, C4.2, J4.2, J5.3, J6.1 (GND), J6.3 (GND), J6.5 (GND), J6.7 (GND), J6.9 (GND), J6.11 (GND), J6.13 (GND), U5.2 (GND), U6.2 (GNDADC), U6.3 (VCCBATT), Y1.3
unnamed: 240ohm1.1, 540ohm1.2, D1.1 (K), U4.1 (ADJ)
unnamed: J1.1, U3.109 (PT28B/VREF2_1)
unnamed: J1.2, U3.110 (PT28A/VREF1_1)
unnamed: J1.3, U3.113 (PT21B)
unnamed: J1.4, U3.114 (PT20B/PCLKC1_0)
unnamed: J6.6 (TCK), R12.1
unnamed: J6.10 (TDI), R14.1
unnamed: J6.8 (TDO), R13.1
unnamed: J6.4 (TMS), R11.1
unnamed: J7.1, U6.4 (TMS)
unnamed: J4.1, SW1.1 (A)
unnamed: 10µF1.1, 10µF3.1, J4.3, SW1.2 (B), U4.3 (VI), U5.1 (VI)
unnamed: U1.12 (CA1), U3.144 (PT8A/ULC_GPLLT_IN_A)
unnamed: U1.9 (CA2), U3.143 (PT7A/VREF1_0)
unnamed: U1.8 (CA3), U3.142 (PT8B/ULC_GPLLC_IN_A)
unnamed: U1.6 (CA4), U3.141 (PT7B/VREF2_0)
unnamed: R8.1, U1.3 (DPX)
unnamed: R1.1, U1.11 (a)
unnamed: R2.1, U1.7 (b)
unnamed: R3.1, U1.4 (c)
unnamed: R4.1, U1.2 (d)
unnamed: R5.1, U1.1 (e)
unnamed: R6.1, U1.10 (f)
unnamed: R7.1, U1.5 (g)
unnamed: U2.12 (CA1), U3.138 (PT9A/ULC_GPLLT_FB_A)
unnamed: U2.9 (CA2), U3.137 (PT9B/ULC_GPLLC_FB_A)
unnamed: U2.8 (CA3), U3.134 (PT13A)
unnamed: U2.6 (CA4), U3.133 (PT13B)
unnamed: R8.2, U2.3 (DPX), U3.121 (PT18B)
unnamed: R1.2, U2.11 (a), U3.130 (PT14B)
unnamed: R2.2, R3.2, U2.4 (c), U2.7 (b), U3.127 (PT16A), U3.129 (PT15B)
unnamed: R4.2, U2.2 (d), U3.125 (PT16B)
unnamed: R5.2, U2.1 (e), U3.124 (PT17A)
unnamed: R6.2, U2.10 (f), U3.123 (PT18A)
unnamed: R7.2, U2.5 (g), U3.122 (PT17B)

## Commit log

2025-07-31 Updated data
    [Pin_Mapping.ods]
2025-07-31 Updated Files
    [5V_Reg.PcbDoc, 5V_Reg.SchDoc, FINAL_PROJECT.kicad_pcb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]
2025-08-04 Kicad_Files Added
    [ADPATIVE BOARD.kicad_pcb, ADPATIVE BOARD.kicad_sch, BGA196C100P14X14_1500X1500X155.PcbLib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]
